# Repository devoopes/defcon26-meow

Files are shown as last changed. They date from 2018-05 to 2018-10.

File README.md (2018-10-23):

# DEFCON 26 - Maneki-neko Badge

  

photo by [Roberto Baldwin](https://twitter.com/@strngwys)  

Follow the Twitter for updates [@ManekiNekoDC](https://twitter.com/ManekiNekoDC)  

We went to DEF CON 26 and launched an unofficial DEF CON badge. We wanted to be able to create something different and unique to some of the other designs out there. The badge is controlled by an STM32 that drives the servo and dual 16 segment LEDS on the front. We attached a 3d printed arm to the servo. All the files are source code are Open Source and in this repo. You are welcome to make one yourself via OSHpark or JLC PCB. Gerber files are located in the repo.  

### Art Design:
Our art was done by Jeff Chang.
http://www.jeffchangart.com/  
Twitter [@jeffchangart](https://twitter.com/jeffchangart)  
Instagram [@jeffchangart](https://instagram.com/jeffchangart)  

All the drafts, and formats of the art can be found in the /art/ directory.

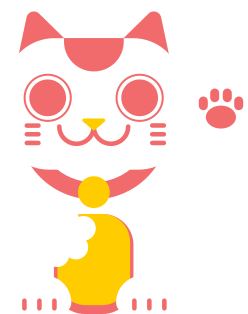
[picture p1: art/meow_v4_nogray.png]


Lanyards were done by https://customlanyards4all.com
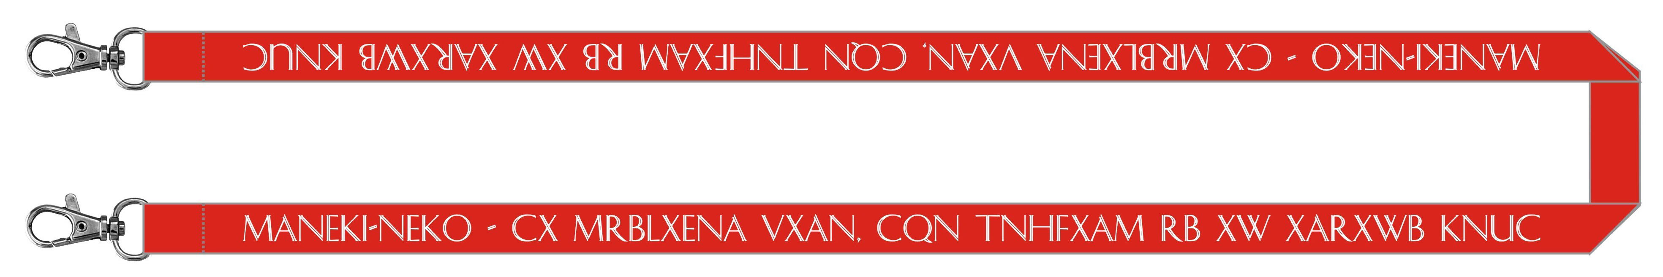
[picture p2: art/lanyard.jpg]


### Meowtronics

First done with KiCAD but abandoned after more experienced help was provided. <3 \
You can find all the Eagle files in the [eagle directory](https://github.com/SeanLeftBelow/defcon26-meow/tree/master/pcb/eagle).

Board is on [OSHpark](https://oshpark.com/shared_projects/X3Hxcson)

Guide is [here](https://github.com/SeanLeftBelow/defcon26-meow/tree/master/guide)

First look at the boards from the fab house.  
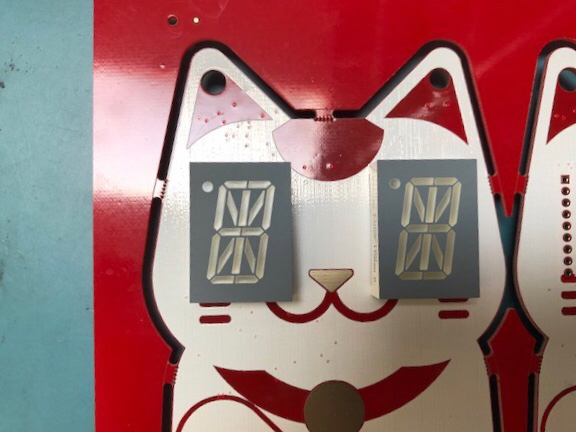
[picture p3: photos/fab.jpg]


### SAO (Special Addons/ Shitty Addons)

Overall design is a copy of the main badge. See writeup [here](https://github.com/SeanLeftBelow/defcon26-meow/tree/master/addon)

### In The Mews

[Engadget: This cute Def Con badge beckons you to hack  it](https://www.engadget.com/2018/08/15/this-cute-def-con-badge-beckons-you-to-hack-it/  ) \
[Hackaday: ALL THE BADGES OF DEF CON 26 (VOL 1)](https://hackaday.com/2018/08/14/all-the-badges-of-def-con-26-vol-1/) \
[BadgeLife - A Hackaday Documentary](https://www.youtube.com/watch?v=G2fHKRONc6U) \

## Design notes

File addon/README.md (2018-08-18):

# Overview
This folder contains the in-progress files for a Maneki-Neko "Simple* Add-On" as per the [Simple Add-On Standard](https://hackaday.com/2018/06/21/this-is-the-year-conference-badges-get-their-own-badges/).

**Note** Documentation is still in progress

BIG Thank You's go to [Contextual Electronics](https://www.youtube.com/channel/UCkJRycUz2CylxpiP-zMePow) for the YouTube Getting to Blinky Series.

This was the most useful tutorial that I referred to while going through the process. If you have the opportunity to read or watch through the entire thing before starting, I highly recommend it as this gives you a fair amount of context.

# Making the Add-On!

1. Create Project
Open KiCad and create a new project. A blank layout and schematic will be created when you create the project.

2. Open Schematic
There are many ways to do this. You can:

- Double-click the .sch file
- Click the Eeschema Launcher shortcut
- Click Command + E
- Go to Tools --> Run Eeschema

3. Create Library and Library Items
- Open Library Editor
- Create component for the connector

4. Build Schematic
- Open Schematic Editor
- Add components to the schematic: LEDs, Resistors, Connector
- Add wiring for components
- Annotate schematic
- Run Error Rule Checking

5. Create Net List

6. Create Layout
- Run PCBNew to create layout
- Go back to Schematic Editor
- Click icon for CvPcb to associate schematic components with component footprints for Layout

7. Add Footprint for Add-on connector
- Go to Footprint Editor
- Add Footprint
- Save footprint to new library
- Add Footprint Libraries Wizard

8. Layout PCB
- Layout components so that ratsnest wires do not cross connect

9. Define Edge Cut layer
(prepare for frustration, desperation, time loss, or maybe everything just goes according to plan!)
- Create DXF file for Import based on solid outline
- @TODO add details on best practices for creating a good DXF for import
- Note that dimensions should match

10. Import Silkscreen Image
- Create silkscreen as footprint and import using BMP to Component tool
- @TODO add details
- There may be some trial and error to get the dimensions to match
- 1000x1000 px resolution png with inverted colors ended up with the best results (light image dark background)
- Import to silk layer

11. Setup Copper Layers
- Create copper layers as individual images and import using BMP to Component tool
- @TODO add details
- There may be some trial and error to get the dimensions to match
- 1000x1000 px resolution png with inverted colors ended up with the best results (light image dark background)
- Import to .... F.Cu layer?

NOTES:
- The program assumes arbitrary input resolution of 300ppi, so a 300 by 300 image will give a 1" by 1" logo on the board.
- According to Best Practices, minimize the number of right angles as you layout the tracks/traces between components on your board.

Want to learn more about PCB Layout and solder mask?
https://learn.sparkfun.com/tutorials/pcb-basics/composition
https://learn.sparkfun.com/tutorials/beginners-guide-to-kicad/editing-a-pcb-layout

Other Resources and Links:
https://medium.com/@urish/a-practical-guide-to-designing-pcb-art-b5aa22926a5c

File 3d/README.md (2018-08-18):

## Arm Spec

Current badge size is 12.5 tall x 7.5 wide. Exact spec is in the eagle files.

You can find the servo horn spec online. Its very commonly available and a set standard.

Arm lengths are:
- 5.5cm tall
- 1.5cm deep
- 2cm wide

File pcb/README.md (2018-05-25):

# PCB Meow

## Libraries:
- ESP Lib: https://github.com/jdunmire/kicad-ESP8266

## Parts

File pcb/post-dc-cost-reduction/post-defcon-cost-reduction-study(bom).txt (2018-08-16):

cost reduction study

=====

no-populations only, no PCB design change

refdes	cost@50		p/n					mfg				link

sw1		0.1462		PTS645SM43SMTR92	c&k				https://www.digikey.com/product-detail/en/c-k/PTS645SM43SMTR92-LFS/CKN9112CT-ND/1146934
h1		0.7280		20021121-00010T4LF	amphenol fci	https://www.digikey.com/products/en?keywords=20021121-00010T4LF
u3		1.0010		NPTC042KFMS-RC		sullins			https://www.digikey.com/products/en?keywords=NPTC042KFMS-RC
u4		0.2368		MIC2005A-1YM5-TR	microchip		https://www.digikey.com/product-detail/en/microchip-technology/MIC2005A-1YM5-TR/576-3462-1-ND/2062462

total	2.1120

=====

cost reduction with minimal pcb design change

refdes	cost@50		p/n					mfg				notes							link

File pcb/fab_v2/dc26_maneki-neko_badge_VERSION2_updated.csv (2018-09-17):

Qty | Value | Device | Package | Parts
2 | 0 ohms | R-US_R0805 | R0805 | R1, R3
6 | 10k/5% | R-US_R0805 | R0805 | R21, R22, R26, R27, R28, R30
2 | 10uF/16V/X5R | C-USC0805 | C0805 | C1, C2
1 | 1k/5% | R-US_R0805 | R0805 | R25
6 | 1uF/16V/X7R | C-USC0805 | C0805 | C6, C7, C9, C10, C11, C12
17 | 270/5% | R-US_R0805 | R0805 | R4, R5, R6, R7, R8, R9, R10, R11, R12, R13, R14, R15, R16, R17, R18, R19, R20
1 | CIG22L4R7MNE | CIG22L4R7MNE | L-1008-US | L1
1 | JS202011SCQN | JS202011SCQN | SW_JS202011SCQN | S1
1 | PAM2301CAAB330 | PAM2301CAAB330 | SOT95P280X100-5N | U2
2 | PSA08-11SRWA | PSA08-11SRWA | PSA08-11SRWA | D1, D2
1 | RK7002BMT116 | NMOSSOT23 | SOT-23 | T1
1 | M20-7870246 | M20-7870246 | 2X2-0.1INCH-FEMALE-SMT | H3
1 | STM32F030C6T6TR | STM32F030C6T6TR | LQFP48 | U1

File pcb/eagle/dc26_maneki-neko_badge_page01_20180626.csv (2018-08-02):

Part | Value | Device | Package | Description | AVAILABILITY | DESCRIPTION | MF | MP | MPN | OC_FARNELL | OC_NEWARK | PACKAGE | PRICE | SPICEPREFIX
C1 | 10uF/16V/X5R | C-USC0805 | C0805 | CAPACITOR, American symbol |  |  |  |  |  |  |  |  |  | C
C2 | 10uF/16V/X5R | C-USC0805 | C0805 | CAPACITOR, American symbol |  |  |  |  |  |  |  |  |  | C
C3 | SHORT | C-USC0805 | C0805 | CAPACITOR, American symbol |  |  |  |  |  |  |  |  |  | C
C4 | 1uF/16V/X7R | C-USC0805 | C0805 | CAPACITOR, American symbol |  |  |  |  |  |  |  |  |  | C
C5 | 1uF/16V/X7R | C-USC0805 | C0805 | CAPACITOR, American symbol |  |  |  |  |  |  |  |  |  | C
C6 | 1uF/16V/X7R | C-USC0805 | C0805 | CAPACITOR, American symbol |  |  |  |  |  |  |  |  |  | C
C7 | 1uF/16V/X7R | C-USC0805 | C0805 | CAPACITOR, American symbol |  |  |  |  |  |  |  |  |  | C
C8 | 1uF/16V/X7R | C-USC0805 | C0805 | CAPACITOR, American symbol |  |  |  |  |  |  |  |  |  | C
C9 | 1uF/16V/X7R | C-USC0805 | C0805 | CAPACITOR, American symbol |  |  |  |  |  |  |  |  |  | C
C10 | 1uF/16V/X7R | C-USC0805 | C0805 | CAPACITOR, American symbol |  |  |  |  |  |  |  |  |  | C
C11 | 1uF/16V/X7R | C-USC0805 | C0805 | CAPACITOR, American symbol |  |  |  |  |  |  |  |  |  | C
C12 | 1uF/16V/X7R | C-USC0805 | C0805 | CAPACITOR, American symbol |  |  |  |  |  |  |  |  |  | C
D1 | PSA08-11SRWA | PSA08-11SRWA | PSA08-11SRWA
D2 | PSA08-11SRWA | PSA08-11SRWA | PSA08-11SRWA
H1 | 20021121-00010T4LF | 20021121-00010T4LF | 20021121-00010T4LF
H2 | M20-8890345R | M20-8890345R | M20-8890345R
H3 | SHITTY-ADDON-HEADER-MASTER | SHITTY-ADDON-HEADER-MASTER | 2X2-0.1INCH-FEMALE-SMT
L1 | CIG22L4R7MNE | CIG22L4R7MNE | L-1008-US
R1 | 0 | R-US_R0805 | R0805 | RESISTOR, American symbol |  |  |  |  |  |  |  |  |  | R
R2 | DNP | R-US_R0805 | R0805 | RESISTOR, American symbol |  |  |  |  |  |  |  |  |  | R
R3 | 0 | R-US_R0805 | R0805 | RESISTOR, American symbol |  |  |  |  |  |  |  |  |  | R
R4 | 270/5% | R-US_R0805 | R0805 | RESISTOR, American symbol |  |  |  |  |  |  |  |  |  | R
R5 | 270/5% | R-US_R0805 | R0805 | RESISTOR, American symbol |  |  |  |  |  |  |  |  |  | R
R6 | 270/5% | R-US_R0805 | R0805 | RESISTOR, American symbol |  |  |  |  |  |  |  |  |  | R
R7 | 270/5% | R-US_R0805 | R0805 | RESISTOR, American symbol |  |  |  |  |  |  |  |  |  | R
R8 | 270/5% | R-US_R0805 | R0805 | RESISTOR, American symbol |  |  |  |  |  |  |  |  |  | R
R9 | 270/5% | R-US_R0805 | R0805 | RESISTOR, American symbol |  |  |  |  |  |  |  |  |  | R
R10 | 270/5% | R-US_R0805 | R0805 | RESISTOR, American symbol |  |  |  |  |  |  |  |  |  | R
R11 | 270/5% | R-US_R0805 | R0805 | RESISTOR, American symbol |  |  |  |  |  |  |  |  |  | R
R12 | 270/5% | R-US_R0805 | R0805 | RESISTOR, American symbol |  |  |  |  |  |  |  |  |  | R
R13 | 270/5% | R-US_R0805 | R0805 | RESISTOR, American symbol |  |  |  |  |  |  |  |  |  | R
R14 | 270/5% | R-US_R0805 | R0805 | RESISTOR, American symbol |  |  |  |  |  |  |  |  |  | R
R15 | 270/5% | R-US_R0805 | R0805 | RESISTOR, American symbol |  |  |  |  |  |  |  |  |  | R
R16 | 270/5% | R-US_R0805 | R0805 | RESISTOR, American symbol |  |  |  |  |  |  |  |  |  | R
R17 | 270/5% | R-US_R0805 | R0805 | RESISTOR, American symbol |  |  |  |  |  |  |  |  |  | R
R18 | 270/5% | R-US_R0805 | R0805 | RESISTOR, American symbol |  |  |  |  |  |  |  |  |  | R
R19 | 270/5% | R-US_R0805 | R0805 | RESISTOR, American symbol |  |  |  |  |  |  |  |  |  | R
R20 | 270/5% | R-US_R0805 | R0805 | RESISTOR, American symbol |  |  |  |  |  |  |  |  |  | R
R21 | 10k/5% | R-US_R0805 | R0805 | RESISTOR, American symbol |  |  |  |  |  |  |  |  |  | R
R22 | 10k/5% | R-US_R0805 | R0805 | RESISTOR, American symbol |  |  |  |  |  |  |  |  |  | R
R23 | NO POP | R-US_R0805 | R0805 | RESISTOR, American symbol |  |  |  |  |  |  |  |  |  | R
R24 | NO POP | R-US_R0805 | R0805 | RESISTOR, American symbol |  |  |  |  |  |  |  |  |  | R
R25 | 1k/5% | R-US_R0805 | R0805 | RESISTOR, American symbol |  |  |  |  |  |  |  |  |  | R
R26 | 10k/5% | R-US_R0805 | R0805 | RESISTOR, American symbol |  |  |  |  |  |  |  |  |  | R
R27 | 10k/5% | R-US_R0805 | R0805 | RESISTOR, American symbol |  |  |  |  |  |  |  |  |  | R
R28 | 10k/5% | R-US_R0805 | R0805 | RESISTOR, American symbol |  |  |  |  |  |  |  |  |  | R
R29 | NO POP | R-US_R0805 | R0805 | RESISTOR, American symbol |  |  |  |  |  |  |  |  |  | R
S1 | JS202011SCQN | JS202011SCQN | SW_JS202011SCQN | JS Series DPDT On-On Gull Wing Surface Mount Subminiature Slide Switch | Good | JS Series DPDT On-On Gull Wing Surface Mount Subminiature Slide Switch | C&K Components | JS202011SCQN |  |  |  | None | 0.33 USD
SW1 | PTS645SM43SMTR92 | PTS645SM43SMTR92 | PTS645SM43SMTR92
T1 | RK7002BMT116 | NMOSSOT23 | SOT-23 | MOS FET |  |  |  |  |  | unknown | unknown
U$2 | BATTPADS-SMT | BATTPADS-SMT | BATTPADS-SMT
U1 | STM32F030C8T | STM32F030C8T | LQFP48 | ARM 32-bit Cortex™-M0 CPU
U2 | PAM2301CAAB330 | PAM2301CAAB330 | SOT95P280X100-5N
U3 | NPTC042KFMS-RC | NPTC042KFMS-RC | NPTC042KFMS-RC
U4 | MIC2005A-1YM5-TR | MIC2005A-1YM5-TR | SOT95P270X145-5N
U5 | MIC2005A-1YM5-TR | MIC2005A-1YM5-TR | SOT95P270X145-5N
U6 | MIC2005A-1YM5-TR | MIC2005A-1YM5-TR | SOT95P270X145-5N

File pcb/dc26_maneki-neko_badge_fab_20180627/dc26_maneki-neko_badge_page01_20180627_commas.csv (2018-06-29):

Designator | Manufacturer Part Number | Quantity
R1,R3 | CRG0805ZR | 2
R21,R22,R26,R27,R28 | RMCF0805JT10K0 | 5
C1,C2 | EMK212BJ106KG-T | 2
R25 | CR0805-JW-102GLF | 1
C4,C5,C6,C7,C8,C9,C10,C11,C12 | CC0805MRY5V7BB105 | 9
H1 | 20021121-00010T4LF | 1
R4,R5,R6,R7,R8,R9,R10,R11,R12,R13,R14,R15,R16,R17,R18,R19,R20 | CR0805-JW-271ELF | 17
L1 | CIG22L4R7MNE | 1
H2 | M20-8890345R | 1
U4,U5,U6 | MIC2005A-1YM5-TR | 3
U3 | NPTC042KFMS-RC | 1
U2 | PAM2301CAAB330 | 1
D1,D2 | PSA08-11SRWA | 2
T1 | RK7002BMT116 | 1
H3 | NPTC022KFMS-RC | 1
U1 | STM32F030C8T6 | 1
S1 | JS202011SCQN | 1
SW1 | PTS645SM43SMTR92 LFS | 1

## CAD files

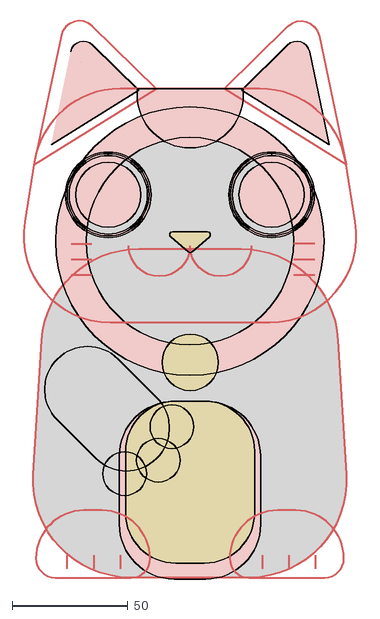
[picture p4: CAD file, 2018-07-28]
art/working files/meow_v4-trace.dxf
150.4 x 243.4

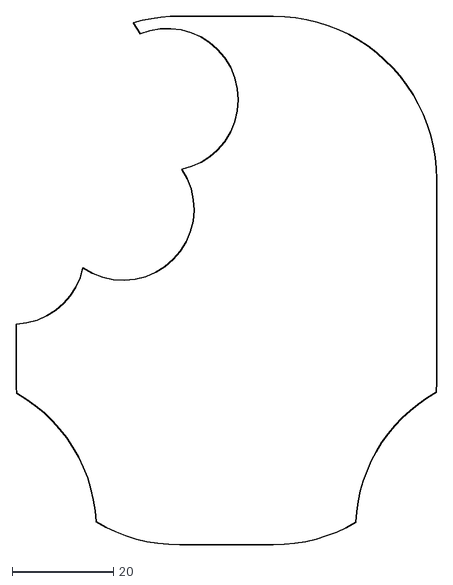
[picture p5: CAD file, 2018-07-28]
pcb/eagle/art prep/meow_v4_coin_fixed.dxf
83.2 x 104.6

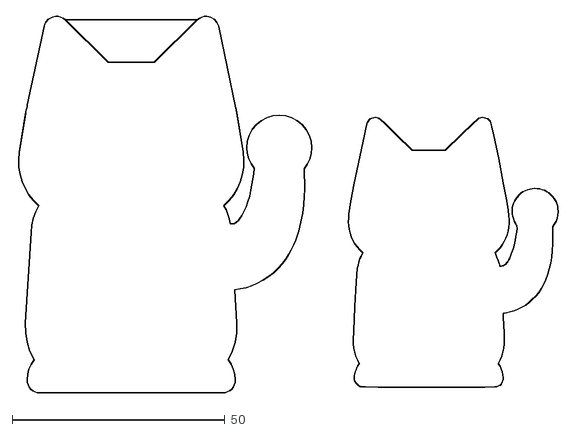
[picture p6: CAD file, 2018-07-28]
art/meow_v4_linedraw-outline-2.5.dxf
127.4 x 88.5

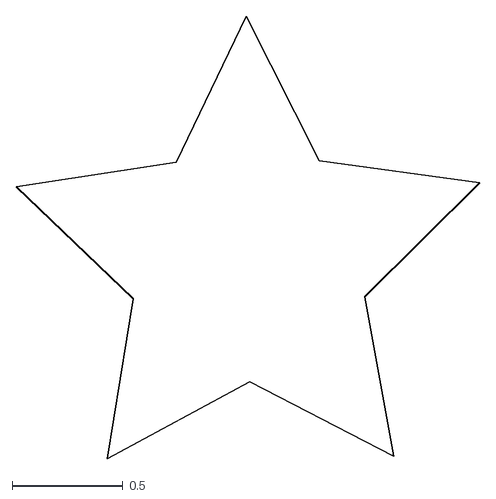
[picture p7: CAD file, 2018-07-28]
art/working files/star.dxf
2.10 x 2.00

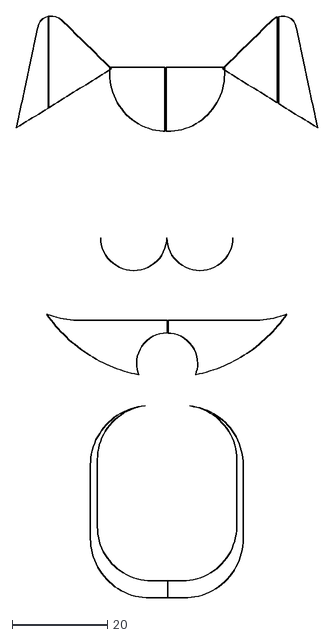
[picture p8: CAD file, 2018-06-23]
pcb/eagle/art prep/meow_v4_redfill2.dxf
63.3 x 122.4

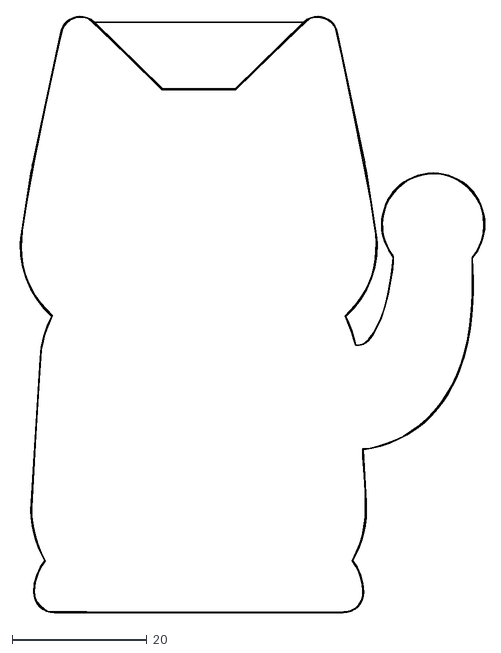
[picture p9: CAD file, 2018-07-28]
art/meow_v4_linedraw-outline.dxf
69.5 x 88.5

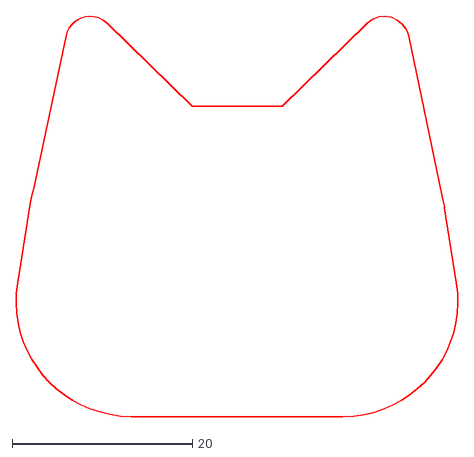
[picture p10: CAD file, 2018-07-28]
art/working files/meow_v5-thick outline-face.dxf
49.1 x 44.5

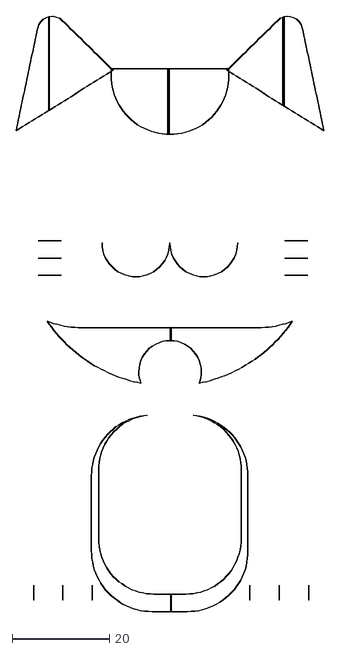
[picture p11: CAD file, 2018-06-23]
pcb/eagle/art prep/meow_v4_redfill.dxf
63.3 x 122.4

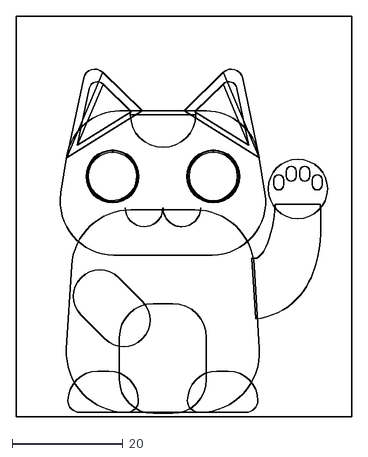
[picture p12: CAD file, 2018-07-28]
art/meow_v4_silk-invert-cu.dxf
60.6 x 72.4

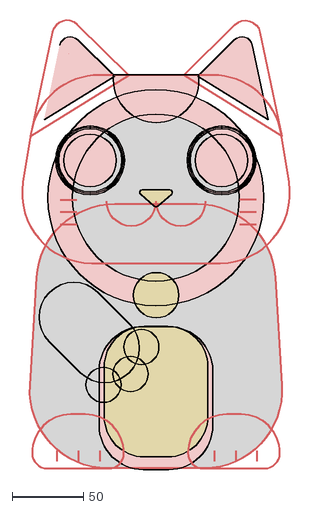
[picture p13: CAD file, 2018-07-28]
art/working files/meow_v4-export.dxf
195.9 x 317.1

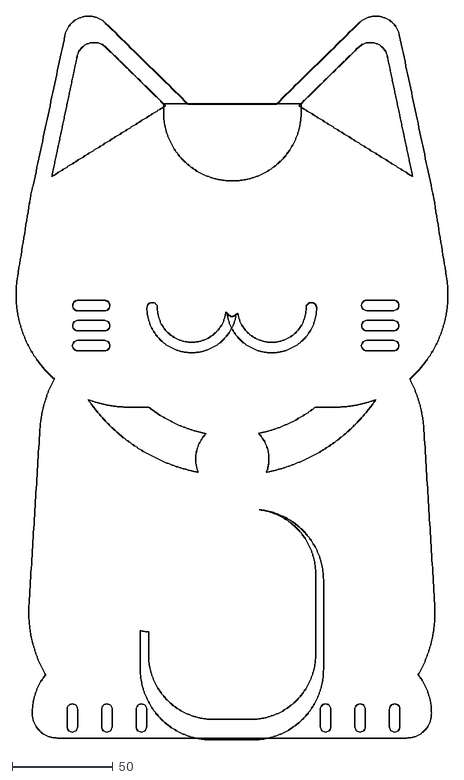
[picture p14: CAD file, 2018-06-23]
pcb/eagle/art prep/meow_v4_silkstop(red).dxf
214.8 x 360.0

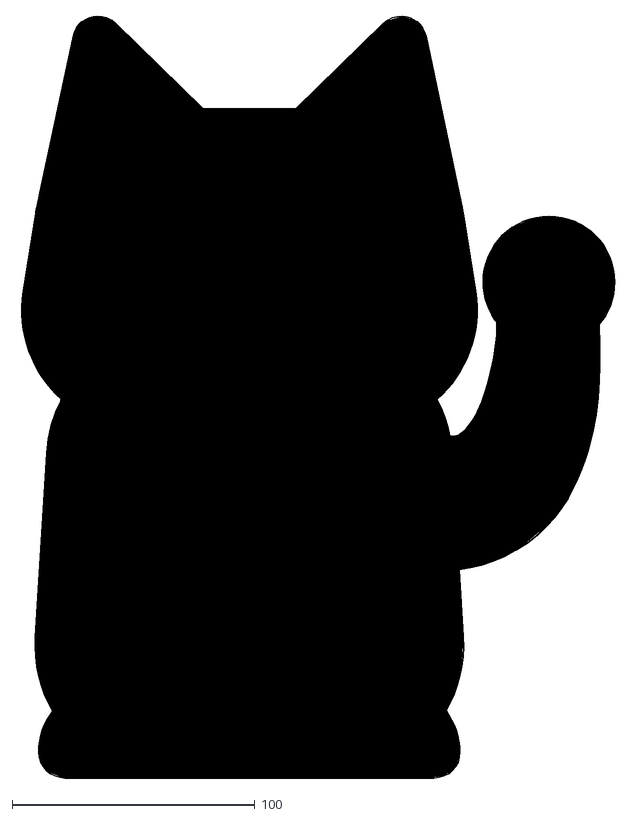
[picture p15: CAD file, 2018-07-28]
art/meow_v4_mask.dxf
246.3 x 313.6

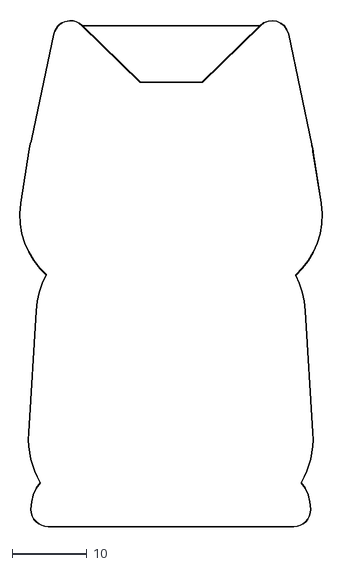
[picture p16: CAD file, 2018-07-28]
art/working files/meow_v5-thick outline.dxf
41.6 x 68.5

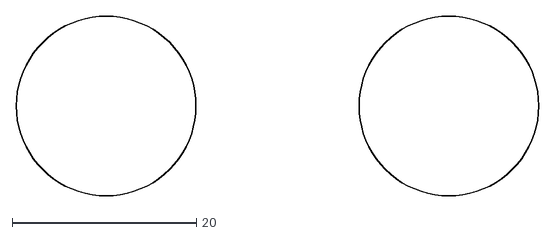
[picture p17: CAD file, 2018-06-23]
pcb/eagle/art prep/meow_v4_eyes.dxf
56.6 x 19.5

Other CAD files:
art/working files/star-lg.dxf
pcb/eagle/art prep/meow_v4_boardoutline.dxf
art/working files/meow_v4.dxf
art/meow_v4_mask-copy.dxf

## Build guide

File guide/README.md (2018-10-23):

# Maneki-neko Badge Assembly Guide

A few have been asking for the ability to build their own from parts. This is a guide to do so.

# DISCLAIMER:
This project is not for the soldering beginner. All the parts are [0603](https://en.wikipedia.org/wiki/Surface-mount_technology#Packages) which are about the size of a grain of sand.

If you wanted to order parts yourself, [Mouser](https://www.mouser.com/) and [Digi-Key](https://www.digikey.com/) are my main resources for parts.

The Bill of Materials (BOM) can be found [here](https://github.com/SeanLeftBelow/defcon26-meow/blob/master/pcb/dc26_maneki-neko_badge_fab_20180627/dc26_maneki-neko_badge_page01_20180627_commas.csv). Sometimes manufacturers discontinue parts or they simply become unavailable. You will have to find alt parts. In my recent order I put together a spreadsheet of purchasable parts and some alts I chose. Speedsheet is [here](https://docs.google.com/spreadsheets/d/13uPpL5BdiQRk4fQEPqo-OPYJxFrPVoP4QA09e1TaAkI/edit?usp=sharing)

If parts become unavailable you can create a PR or DM me on twitter [@ManekiNekoDC](https://twitter.com/ManekiNekoDC) \

## Important Notes about the BOM
- U4,U5,U6, IC PWR SWITCH ACTIVE HI \
    _This part was removed on the second rev of the board and has no place on the board._
- H3	Header 4 Position Dual Row \
    _This part was removed in ver 2 but the pads are still there._
- R30, 10K OHM \
    _This part is only on ver 2._

## Required tools
Soldering Iron with a fine tip (Something you are comfortable working with 0603's with.)\
Leaded/Unleaded Solder \
[Flux](https://www.amazon.com/Tools-Harware-8310000186-Kester-Soldering/dp/B00YL1D3US/) \
[Solder Wick](https://www.amazon.com/NTE-Electronics-SW02-10-No-Clean-Blue-098/dp/B0195UVWJ8/) \
[Tweezers](https://www.amazon.com/gp/product/B0009K3IAK/) (Get good ones. Bad ones can be magnetic.) \
[Magnified Glass](https://www.amazon.com/Spectrum-Natural-Daylight-Magnifier-Mounting/dp/B00D5WM8EG/) or [Microscope](https://www.amazon.com/gp/product/B005C75IVM/) \
[The Programmer](https://www.segger.com/products/debug-probes/j-link/models/j-link-edu-mini/) -  [Amazon](https://www.amazon.com/Segger-J-Link-EDU-mini-Debugger/dp/B0758XRMTF) /  [Adafruit](https://www.adafruit.com/product/3571) \
I used a Segger, but you can get cheaper AVR programmers off Ali and Amazon.

## Soldering the board.
- (**U1**	MCU 32-bit STM32F ARM Cortex) \
_Note: Liberally apply flux when soldering the MCU. If you have not soldered an MCU before please watch a few techniques on YouTube._  
Position the PCB so the head is up and feet down. The MCU is in the top right and the position of the dot is lower left.
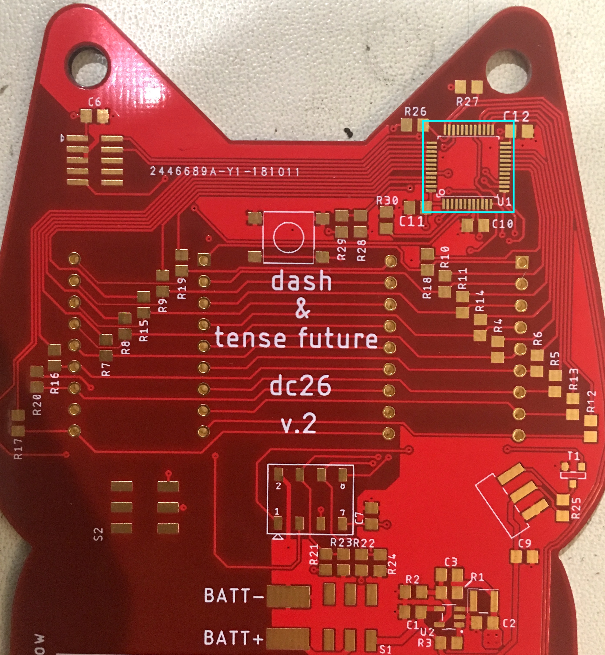
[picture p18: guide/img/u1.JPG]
  

- (**R1,R3** - 0 OHM) \
_Note: R2 and R4 are intentionally left blank_
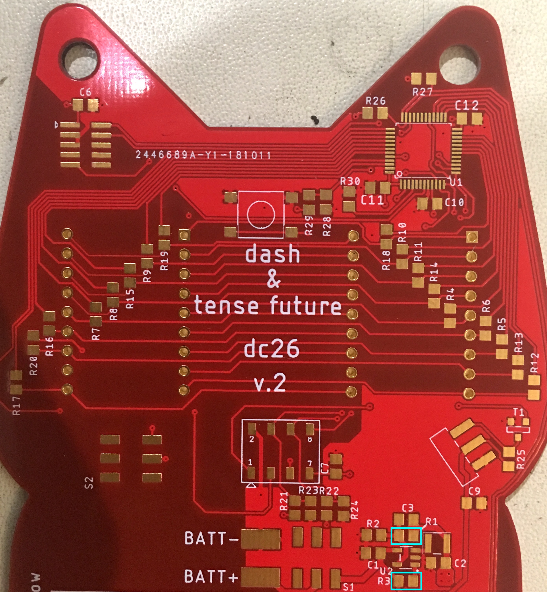
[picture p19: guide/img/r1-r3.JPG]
  

- (**R21,R22,R26,R27,R28,R30**	10K OHM) \
_Note: R23, R24, R29 are intentionally left blank_
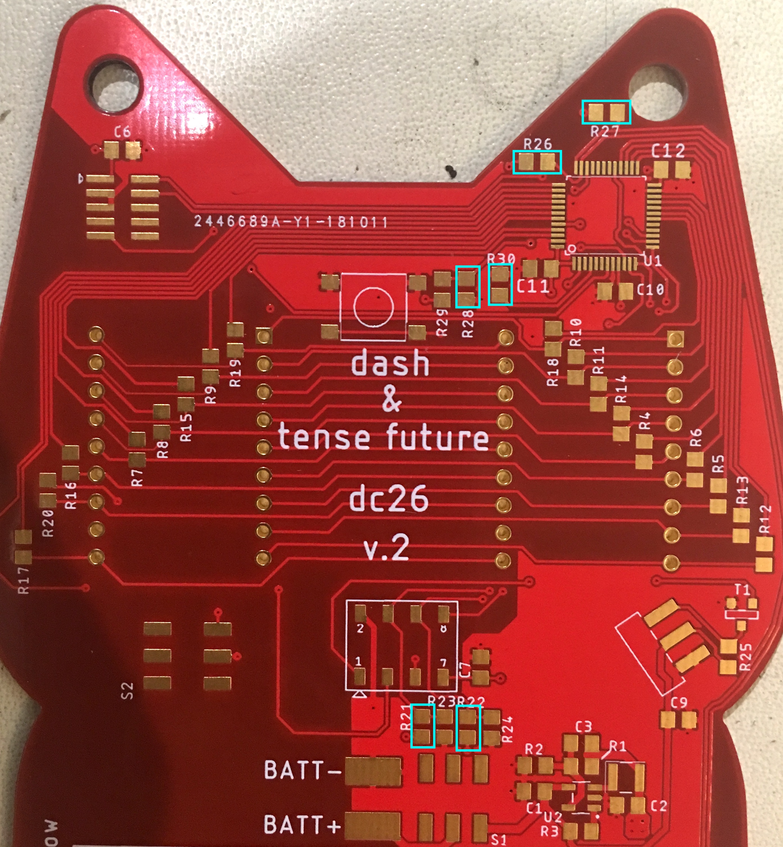
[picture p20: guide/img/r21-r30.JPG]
  

- (**C1,C2** - 10µF ±10% 16V) \
_Note: C3 is intentionally left blank_
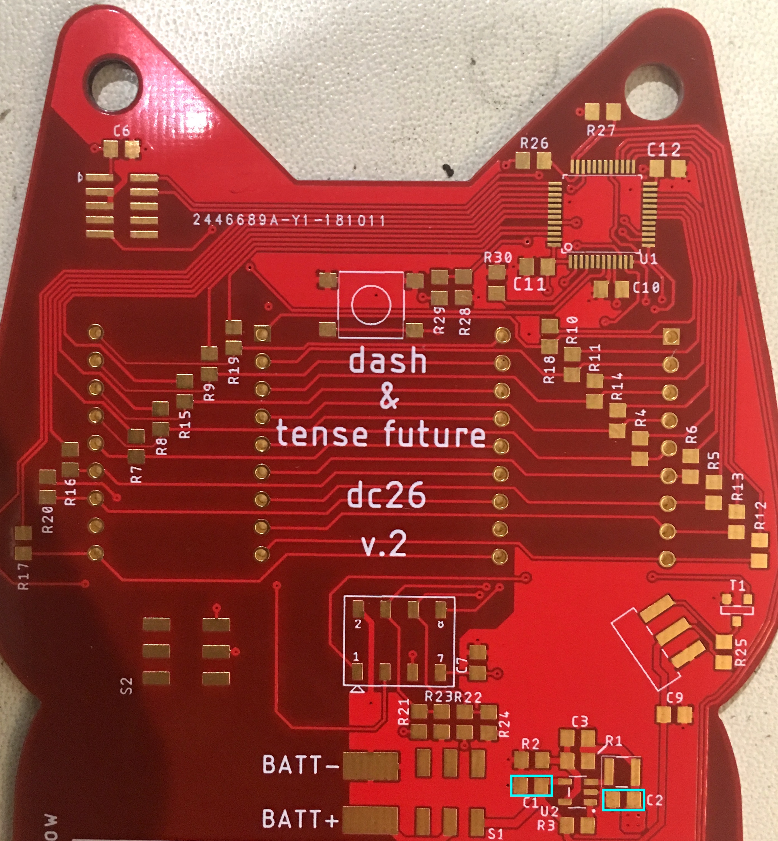
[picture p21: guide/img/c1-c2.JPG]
  

- (**R25** - 1K OHM)
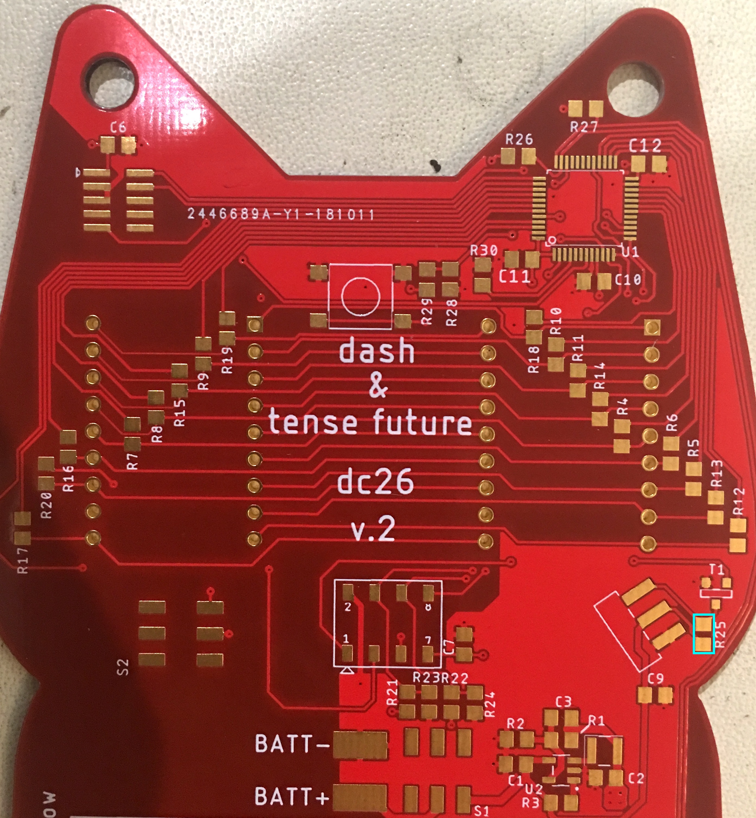
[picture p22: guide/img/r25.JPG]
  

- (**C4,C5,C6,C7,C8,C9,C10,C11,C12**-  1uF 16V) \
_Note: C4, C5, C8 were removed on rev 2_
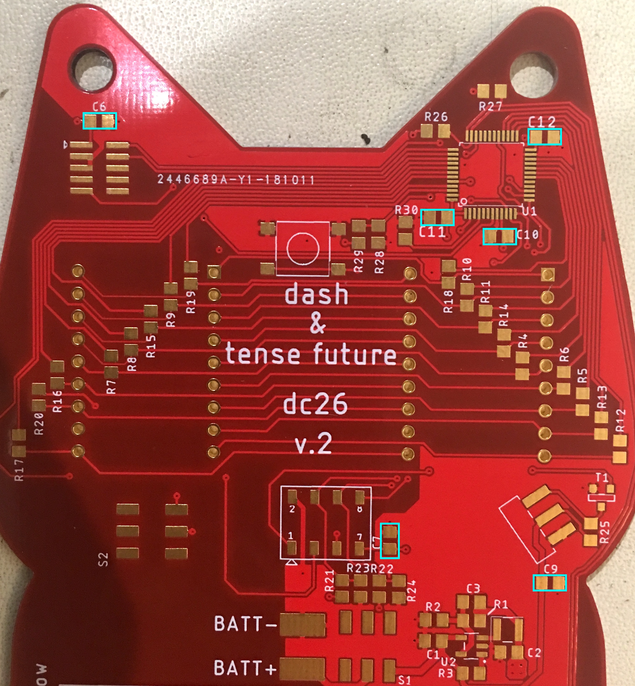
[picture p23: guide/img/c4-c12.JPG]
  

- (**H1**	- 2 Row 10 Position (5x2) 1.27 mm Unshrouded Surface Mount Male Pin Header)
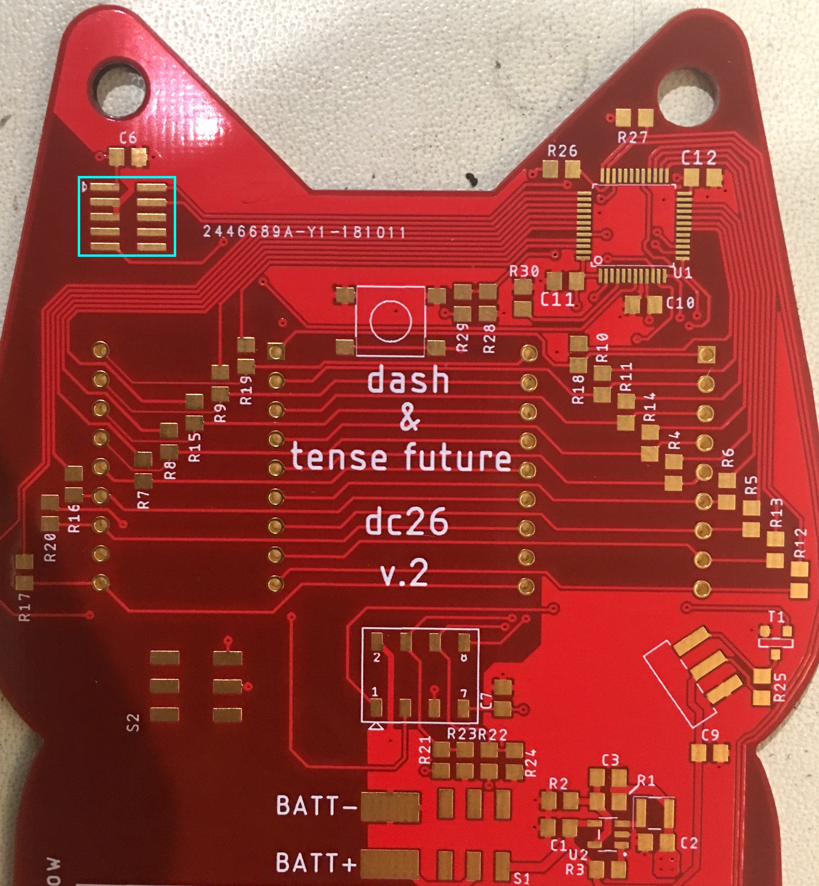
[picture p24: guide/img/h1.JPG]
  

- (**R4,R5,R6,R7,R8,R9,R10,R11,R12,R13,R14,R15,R16,R17,R18,R19,R20**	- 270 OHM)
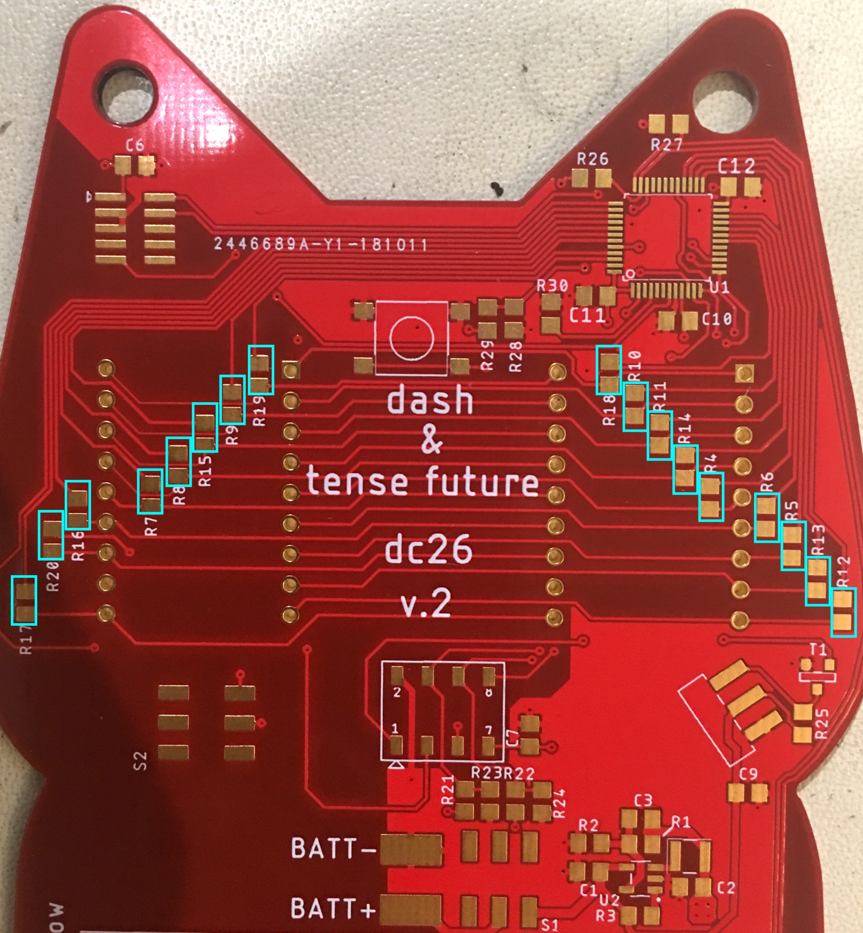
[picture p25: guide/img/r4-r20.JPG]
  

- (**L1**	- 4.7µH Shielded Multilayer Inductor 1.1A) \
_Note: No silkscreen label_
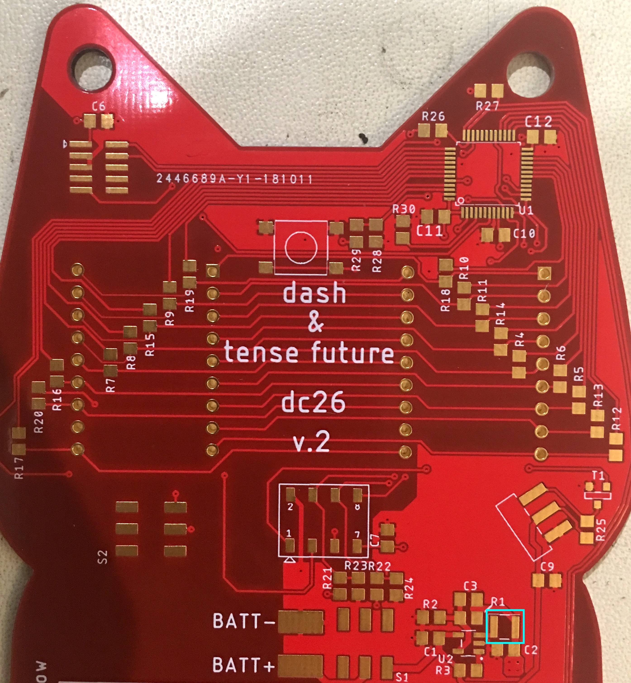
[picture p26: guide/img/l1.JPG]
  

- (**U2**	- IC REG BCK 3.3V 0.8A SYNC)
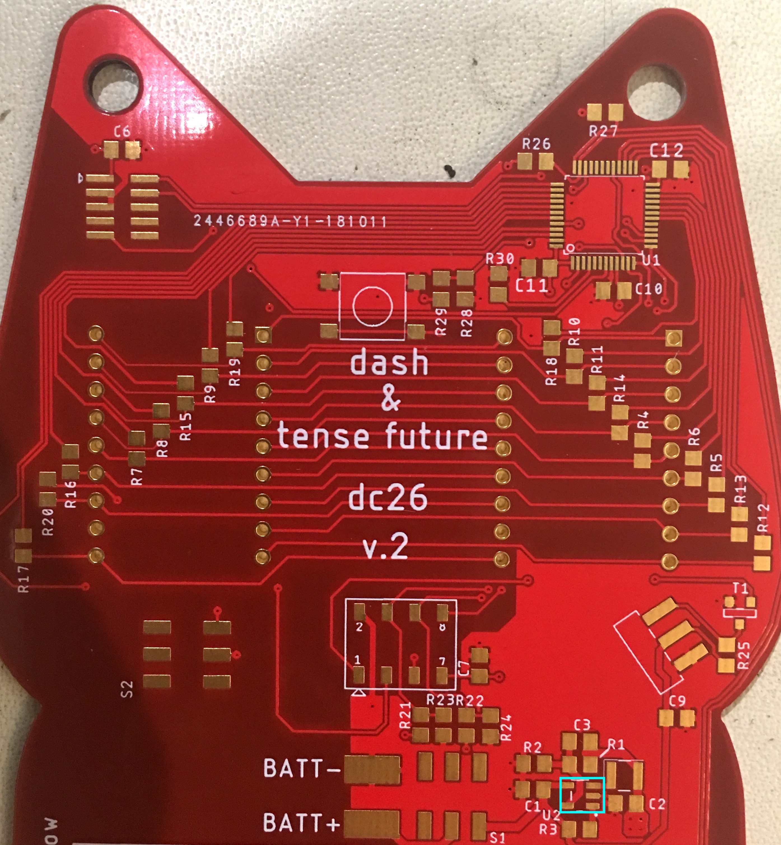
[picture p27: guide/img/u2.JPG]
  

- (**T1**	- 2.5V Drive Nch Mosfet)
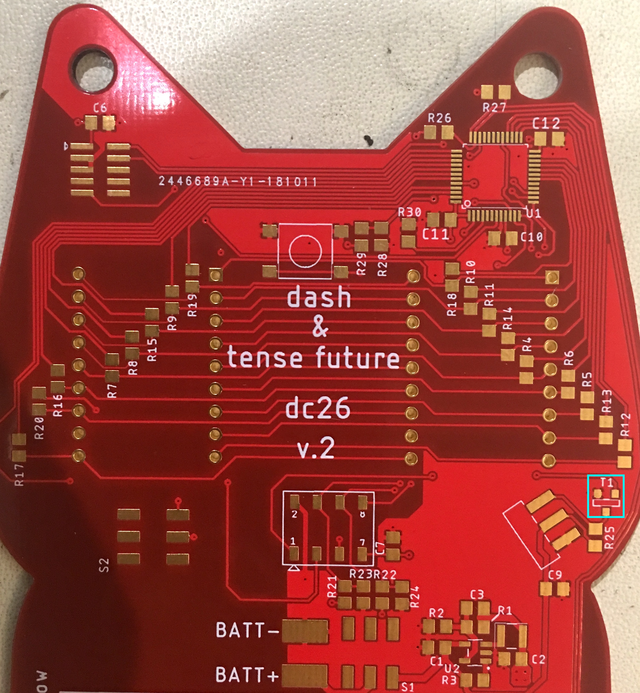
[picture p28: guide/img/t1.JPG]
  

- (**S1** - Switch) \
_Note: This is to the right of the BATT pads. The close up is to show orientation for the off position_
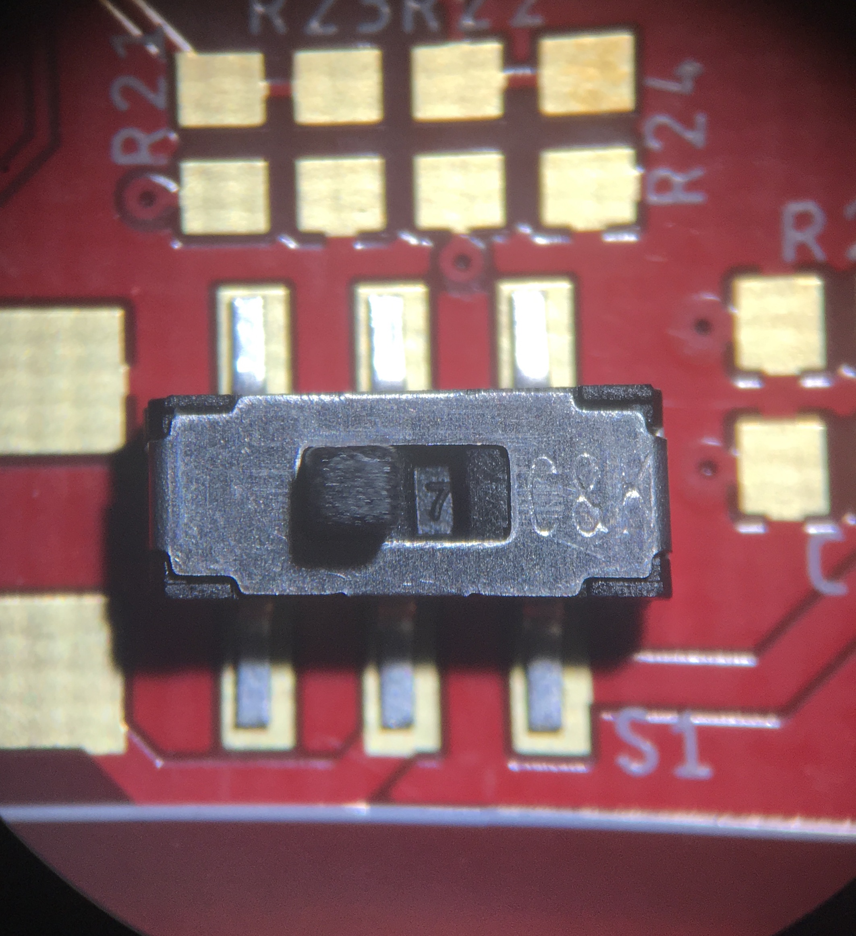
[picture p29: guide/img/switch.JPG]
  

# These parts should be soldered last.

- (**H3**	- Header 4 Position Dual Row)
  

- (**D1,D2** - 16 Segment Display; red) \
_Note: The orientation of the dot is always bottom right_
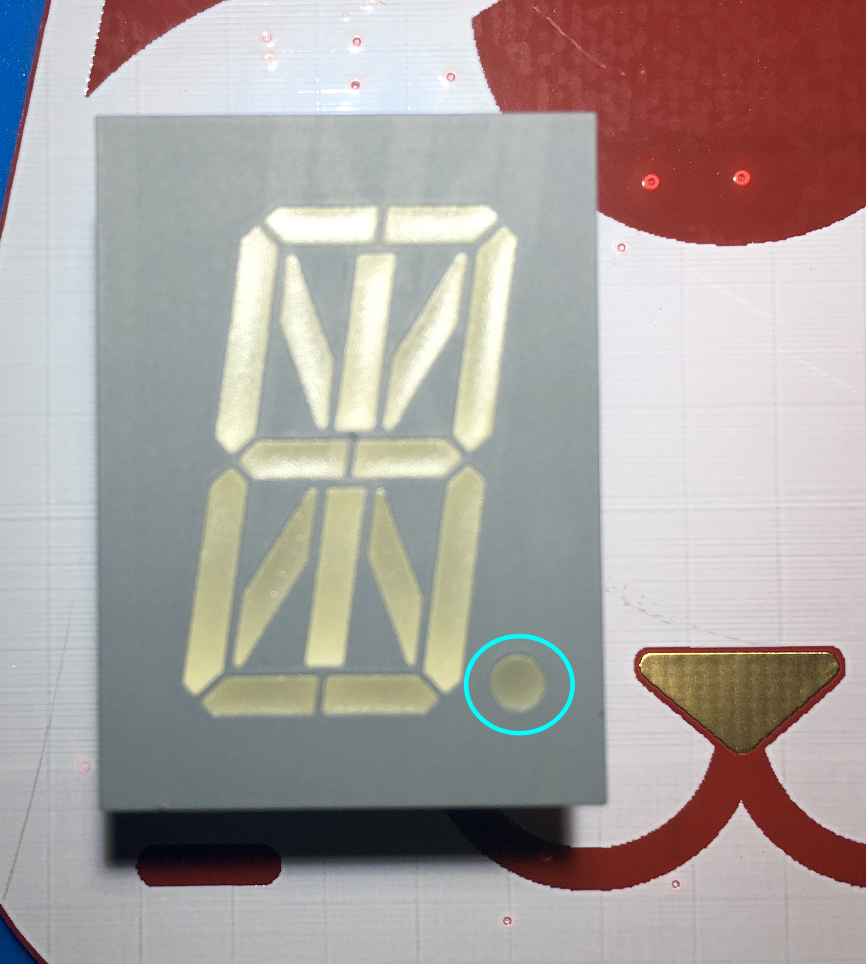
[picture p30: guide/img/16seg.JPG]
  

- (Battery Pack)
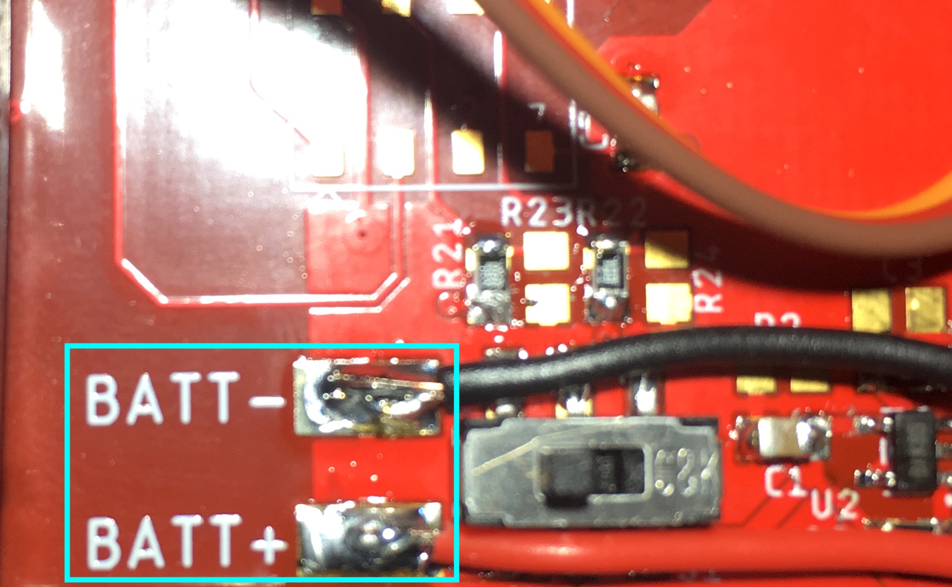
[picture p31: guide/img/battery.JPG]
  

- (Servo) \
_Note: from top to bottom Orange, Red, Brown._
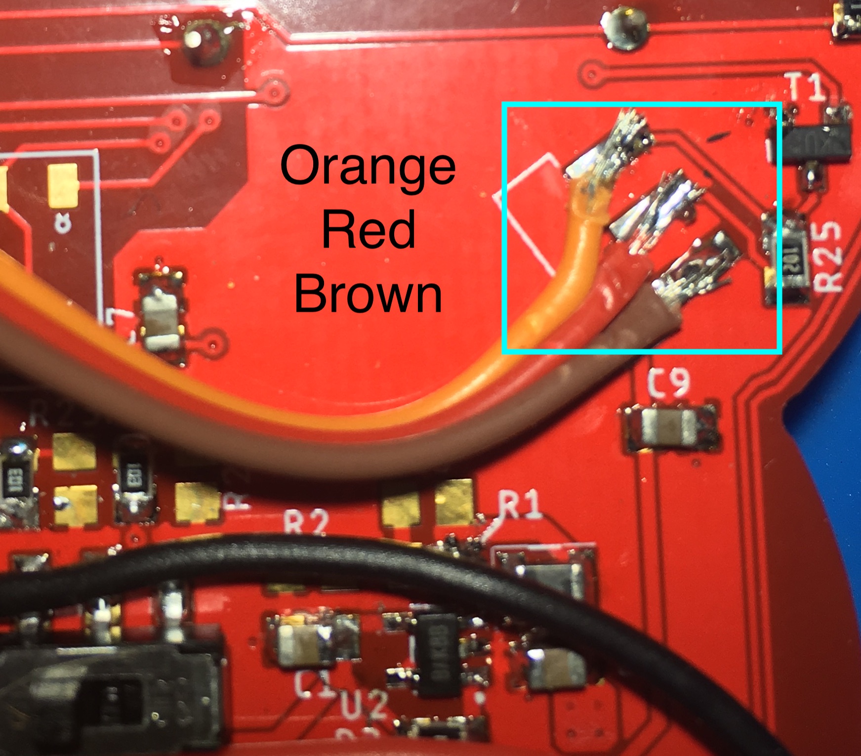
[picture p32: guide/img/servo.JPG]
  

- Once everything is soldered, attach the battery pack and servo with double sided foam tape. The servo will fit perfectly alongside the battery pack.
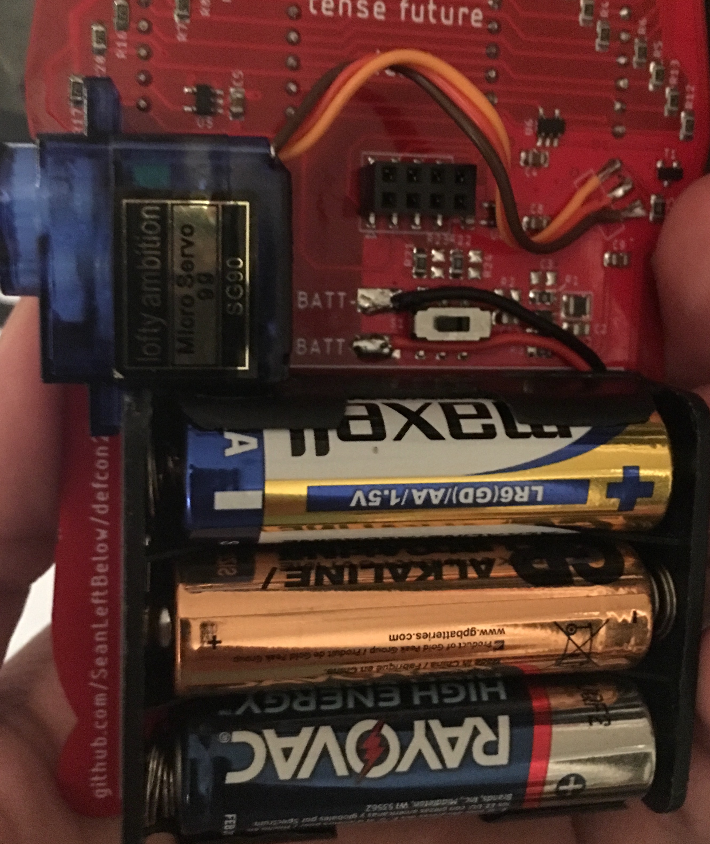
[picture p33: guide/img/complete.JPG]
  

## Keil Setup:

On a windows computer download and install [Keil](http://www2.keil.com/stmicroelectronics-stm32/mdk) \
_Note: in the case this becomes unavailable or the link changes. Google for the `ARM Keil tool for MDK for STM32L0 and STM32F0`_ \
On the same computer clone this repo and open the firmware directory of the repo in Keil.

## Programming the Board.

If you would like to attach a programmer with out having the fitting for the small ribbon the full schematic is available in eagle.

| | | | |
| --- | :---: | :---: | --- |
| v3.3 | **1** | **2** | DLO |
| GND  | **3** | **4** | CLK |
| GND  | **5** | **6** | |
| | **7** | **8** | |
| RST  | **9** | **10** | | |

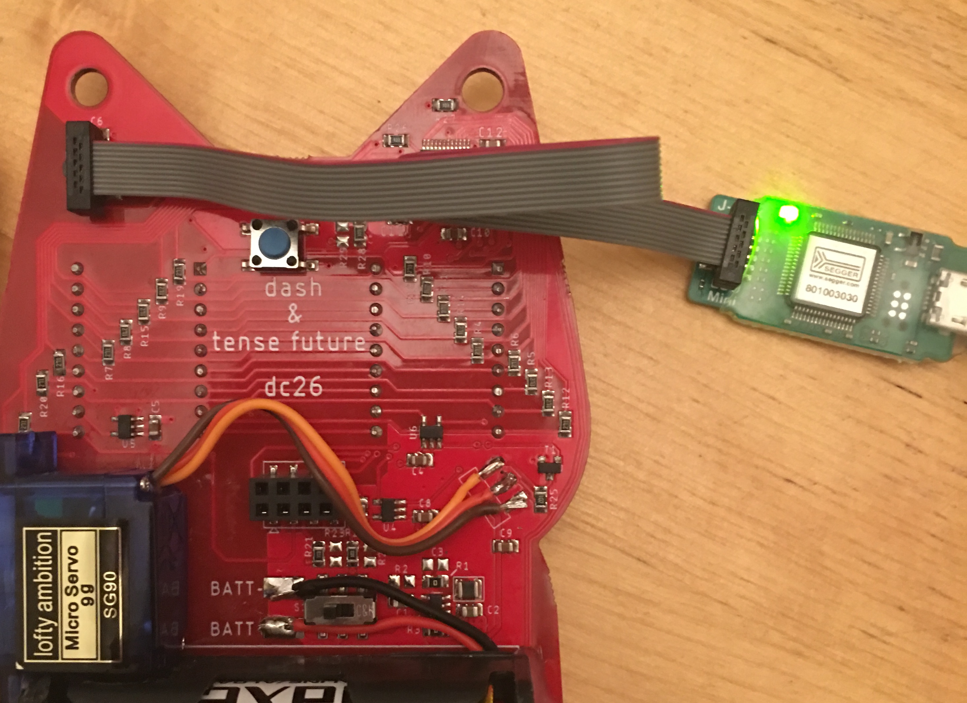
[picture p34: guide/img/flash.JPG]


_Note: Please note the orientation of the ribbon cable._ \
Once Keil is setup, put in batteries, attach the programmer cable and turn the switch to the right. Then click the `LOAD` button in Keil. A prompt will appear with a ToS that you have to accept.
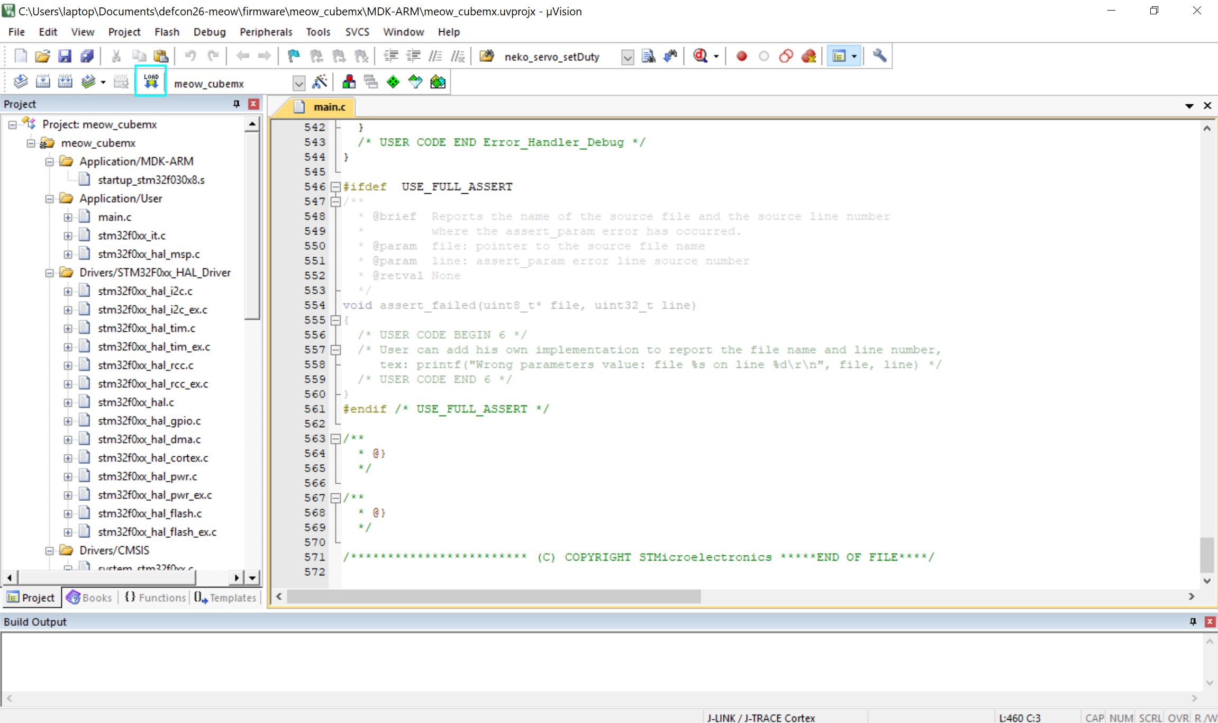
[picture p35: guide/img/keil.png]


If everything is soldered correctly and it's powered it will begin to flash. Once it's programmed the servo will start moving and the eyes will flash.

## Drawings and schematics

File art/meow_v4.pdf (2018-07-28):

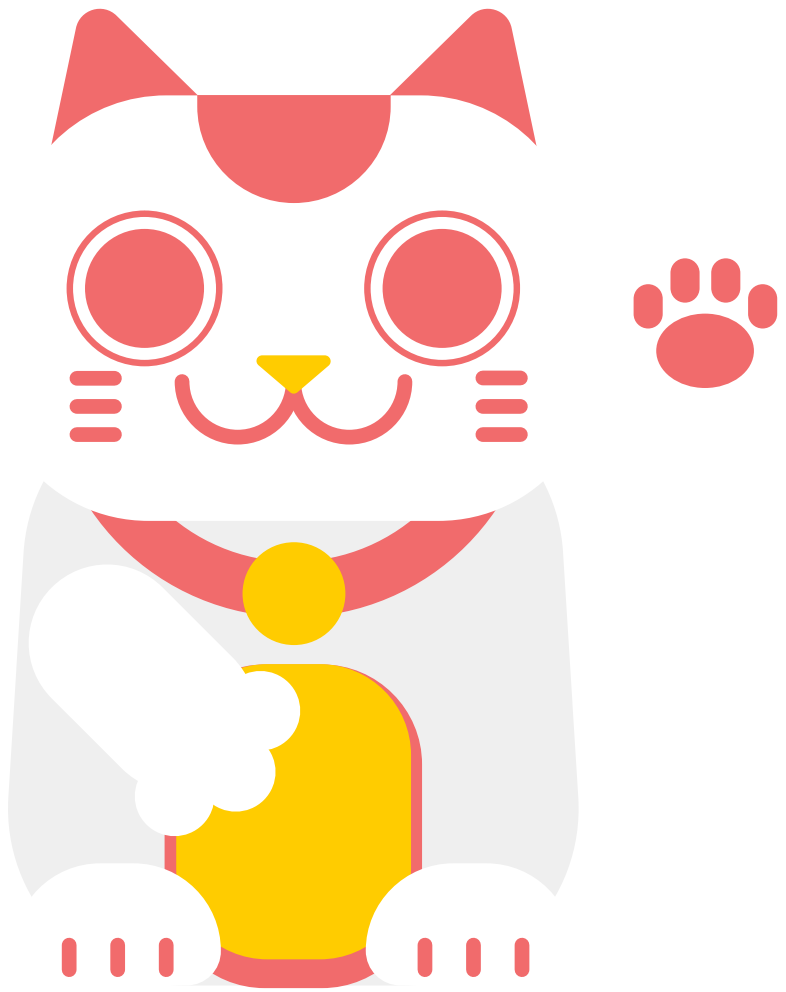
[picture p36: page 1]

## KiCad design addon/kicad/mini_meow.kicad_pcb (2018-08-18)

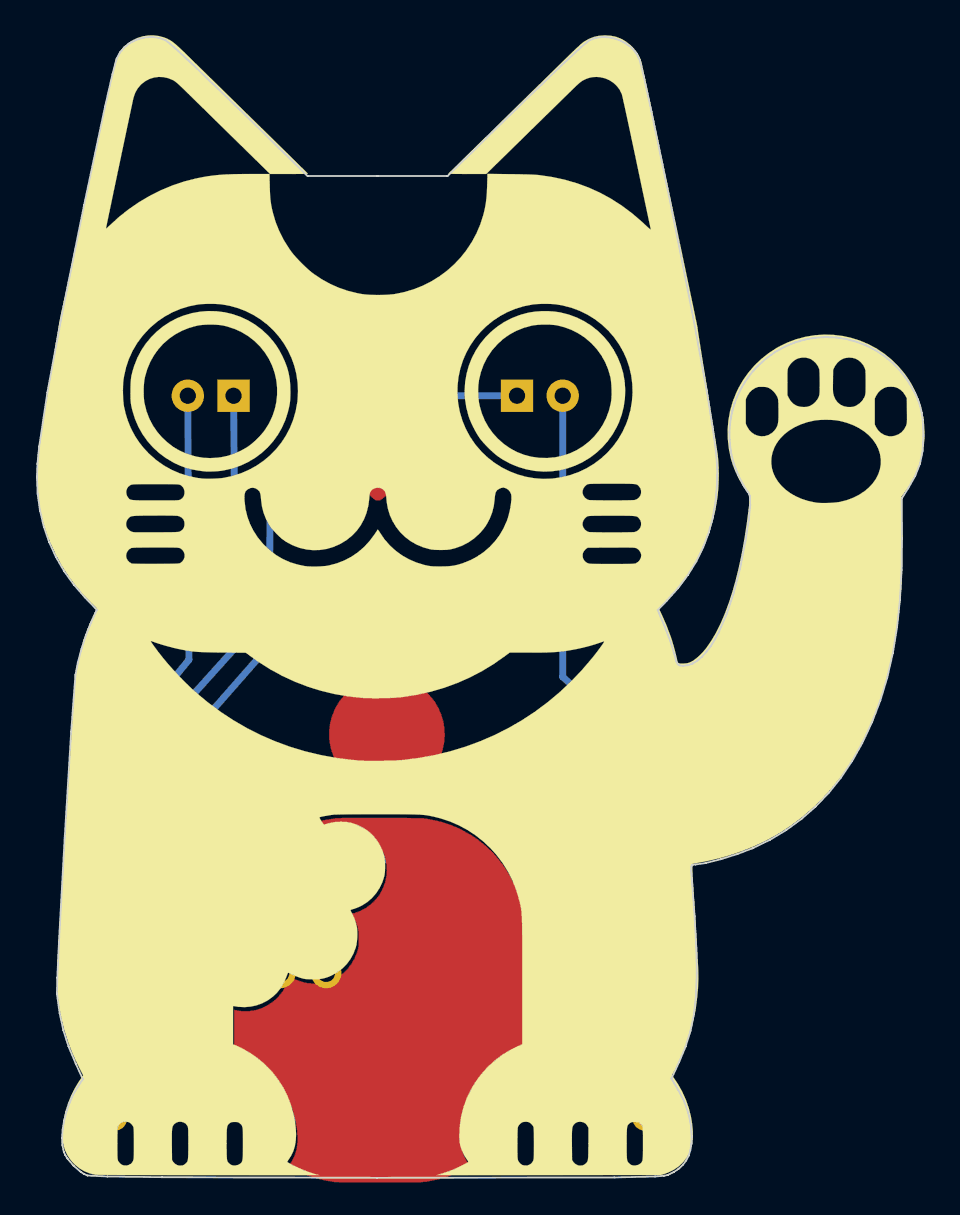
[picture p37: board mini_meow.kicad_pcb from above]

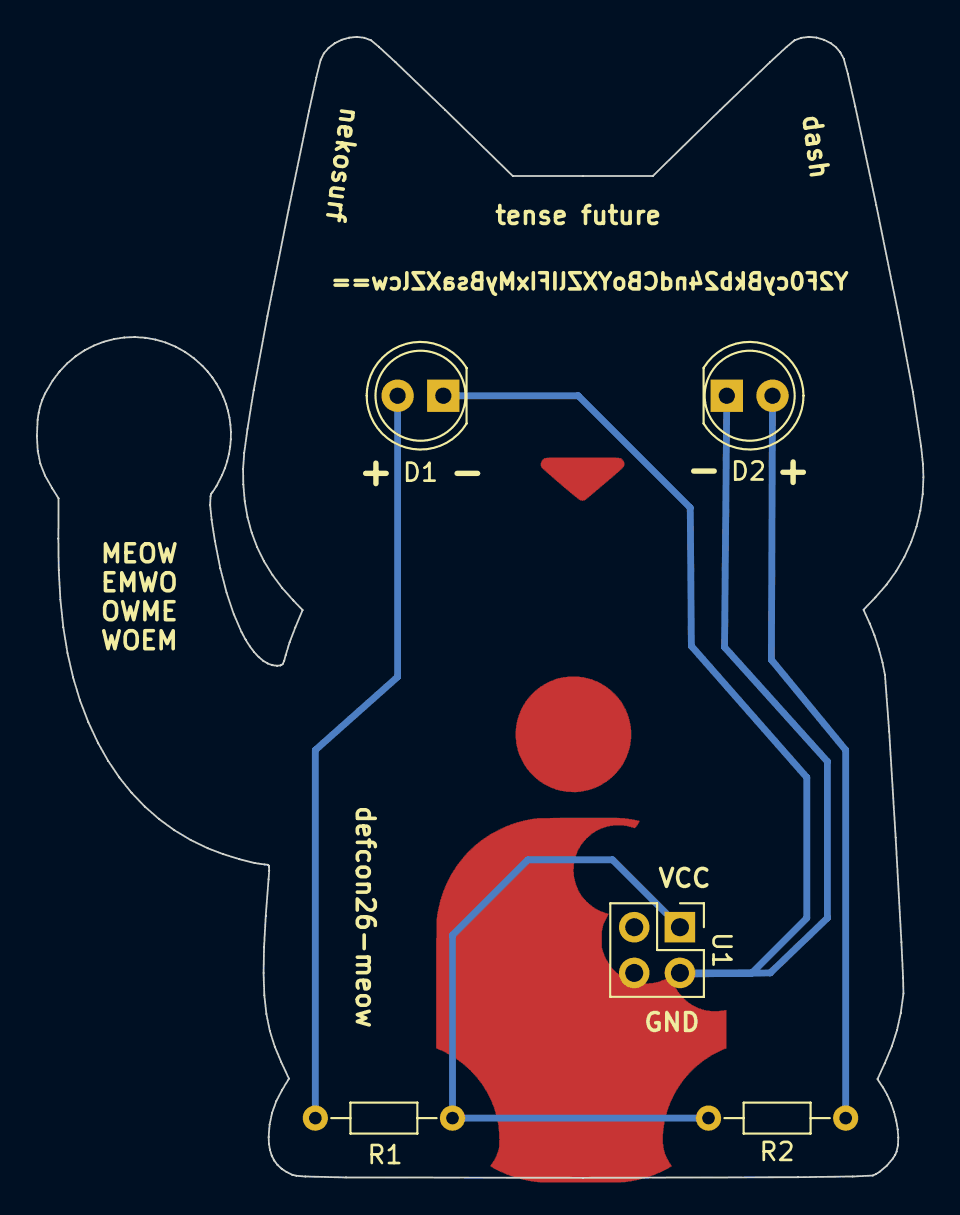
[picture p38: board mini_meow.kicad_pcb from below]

Board: 2 copper layers, 49.3 x 63.4 mm, 5 parts (5 on the bottom side), 4 nets.

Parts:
D1, D2: LED; LED_D5.0mm
R1, R2: 65; R_Axial_DIN0204_L3.6mm_D1.6mm_P7.62mm_Horizontal
U1: sa_connector; Pin_Header_Straight_2x02_Pitch2.54mm

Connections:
+3V3: R1.2, R2.2, U1.1
GND: D1.1, D2.1, U1.2
unnamed: D1.2, R1.1
unnamed: D2.2, R2.1

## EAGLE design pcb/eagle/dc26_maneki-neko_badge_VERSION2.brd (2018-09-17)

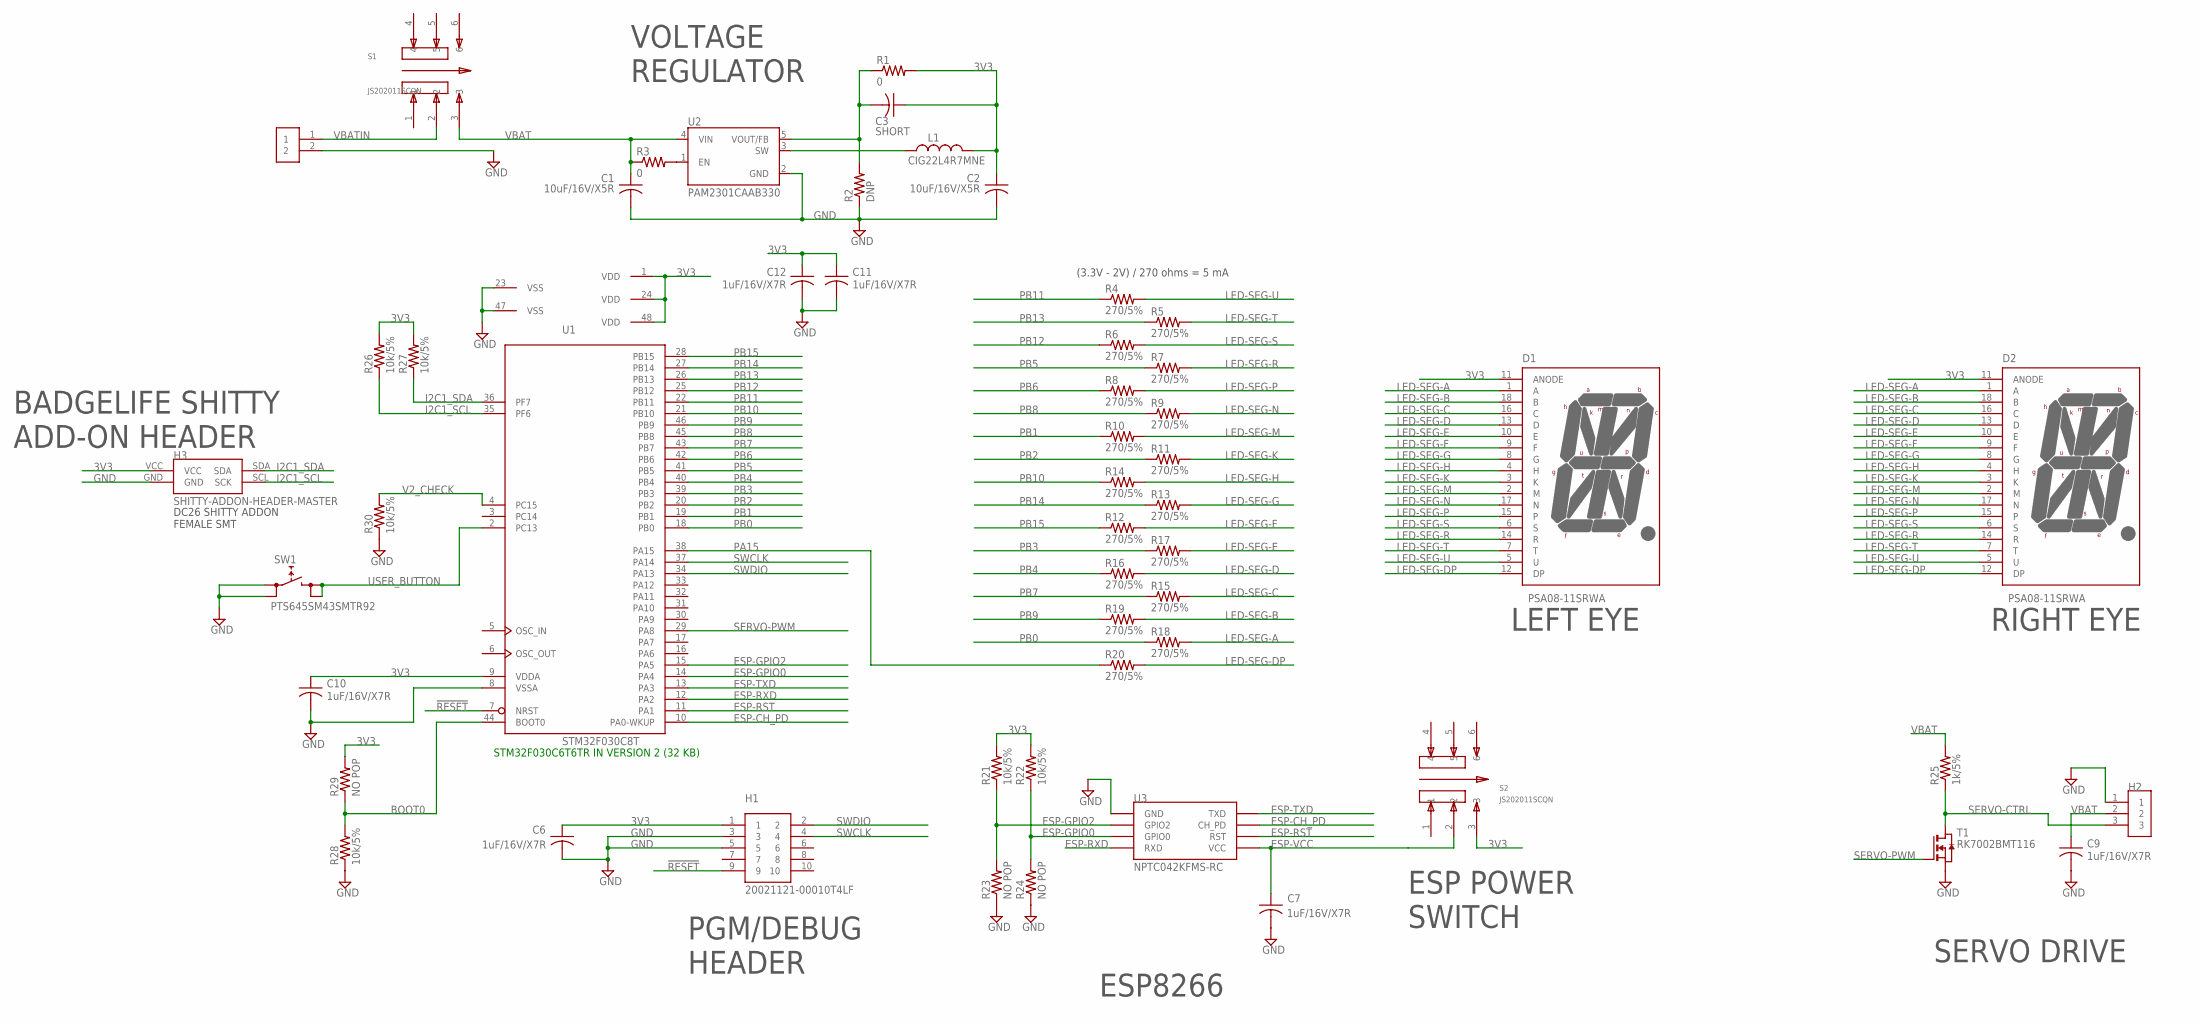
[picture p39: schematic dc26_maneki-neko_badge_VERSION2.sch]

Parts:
C1, C2: 10uF/16V/X5R; C0805
C3: SHORT; C0805
C6, C7, C9, C10, C11, C12: 1uF/16V/X7R; C0805
D1, D2: PSA08-11SRWA
H1: 20021121-00010T4LF
H2: M20-8890345R
H3: SHITTY-ADDON-HEADER-MASTER; 2X2-0.1INCH-FEMALE-SMT
H4: BATTPADS-SMT
L1: CIG22L4R7MNE; L-1008-US
R1, R3: 0; R0805
R2: DNP; R0805
R4, R5, R6, R7, R8, R9, R10, R11, R12, R13, R14, R15, R16, R17, R18, R19, R20: 270/5%; R0805
R21, R22, R26, R27, R28, R30: 10k/5%; R0805
R23, R24, R29: NO POP; R0805
R25: 1k/5%; R0805
S1, S2: JS202011SCQN; SW_JS202011SCQN
SW1: PTS645SM43SMTR92
T1: RK7002BMT116; SOT-23
U1: STM32F030C8T; LQFP48
U2: PAM2301CAAB330; SOT95P280X100-5N
U3: NPTC042KFMS-RC

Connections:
3V3: C2.1, C3.1, C6.1, C10.1, C11.1, C12.1, D1.11 (ANODE), D2.11 (ANODE), H1.1, H3.VCC, L1.P$2 (2), R1.2, R21.2, R22.2, R26.2, R27.2, R29.2, S2.3, U1.1 (VDD), U1.9 (VDDA), U1.24 (VDD), U1.48 (VDD)
!RESET: H1.9, U1.7 (NRST)
BOOT0: R28.2, R29.1, U1.44 (BOOT0)
ESP-CH_PD: U1.10 (PA0-WKUP), U3.3 (CH_PD)
ESP-GPIO0: R22.1, R24.2, U1.14 (PA4), U3.6 (GPIO0)
ESP-GPIO2: R21.1, R23.2, U1.15 (PA5), U3.4 (GPIO2)
ESP-RST: U1.11 (PA1), U3.5 (RST)
ESP-RXD: U1.12 (PA2), U3.8 (RXD)
ESP-TXD: U1.13 (PA3), U3.1 (TXD)
ESP-VCC: C7.1, S2.2, U3.7 (VCC)
GND: C1.2, C2.2, C6.2, C7.2, C9.2, C10.2, C11.2, C12.2, H1.3, H1.5, H2.1, H3.GND, H4.2, R2.1, R23.1, R24.1, R28.1, R30.1, SW1.1 (0), SW1.2 (0), T1.2 (S), U1.8 (VSSA), U1.23 (VSS), U1.47 (VSS), U2.2 (GND), U3.2 (GND)
I2C1_SCL: H3.SCL (SCK), R26.1, U1.35 (PF6)
I2C1_SDA: H3.SDA, R27.1, U1.36 (PF7)
LED-SEG-A: D1.1 (A), D2.1 (A), R18.2
LED-SEG-B: D1.18 (B), D2.18 (B), R19.2
LED-SEG-C: D1.16 (C), D2.16 (C), R15.2
LED-SEG-D: D1.13 (D), D2.13 (D), R16.2
LED-SEG-DP: D1.12 (DP), D2.12 (DP), R20.2
LED-SEG-E: D1.10 (E), D2.10 (E), R17.2
LED-SEG-F: D1.9 (F), D2.9 (F), R12.2
LED-SEG-G: D1.8 (G), D2.8 (G), R13.2
LED-SEG-H: D1.4 (H), D2.4 (H), R14.2
LED-SEG-K: D1.3 (K), D2.3 (K), R11.2
LED-SEG-M: D1.2 (M), D2.2 (M), R10.2
LED-SEG-N: D1.17 (N), D2.17 (N), R9.2
LED-SEG-P: D1.15, D2.15, R8.2
LED-SEG-R: D1.14 (R), D2.14 (R), R7.2
LED-SEG-S: D1.6 (S), D2.6 (S), R6.2
LED-SEG-T: D1.7 (T), D2.7 (T), R5.2
LED-SEG-U: D1.5 (U), D2.5 (U), R4.2
unnamed: L1.P$1 (1), U2.3 (SW)
unnamed: R3.2, U2.1 (EN)
unnamed: C3.2, R1.1, R2.2, U2.5 (VOUT/FB)
PA15: R20.1, U1.38 (PA15)
PB0: R18.1, U1.18 (PB0)
PB1: R10.1, U1.19 (PB1)
PB2: R11.1, U1.20 (PB2)
PB3: R17.1, U1.39 (PB3)
PB4: R16.1, U1.40 (PB4)
PB5: R7.1, U1.41 (PB5)
PB6: R8.1, U1.42 (PB6)
PB7: R15.1, U1.43 (PB7)
PB8: R9.1, U1.45 (PB8)
PB9: R19.1, U1.46 (PB9)
PB10: R14.1, U1.21 (PB10)
PB11: R4.1, U1.22 (PB11)
PB12: R6.1, U1.25 (PB12)
PB13: R5.1, U1.26 (PB13)
PB14: R13.1, U1.27 (PB14)
PB15: R12.1, U1.28 (PB15)
SERVO-CTRL: H2.3, R25.1, T1.1 (D)
SERVO-PWM: T1.3 (G), U1.29 (PA8)
SWCLK: H1.4, U1.37 (PA14)
SWDIO: H1.2, U1.34 (PA13)
USER_BUTTON: SW1.3 (1), SW1.4 (1), U1.2 (PC13)
V2_CHECK: R30.2, U1.4 (PC15)
VBAT: C1.1, C9.1, H2.2, R3.1, R25.2, S1.3, U2.4 (VIN)
VBATIN: H4.1, S1.2

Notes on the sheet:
RIGHT EYE
LEFT EYE
(3.3V - 2V) / 270 ohms = 5 mA
SERVO DRIVE
ESP8266
ESP POWER SWITCH
PGM/DEBUG HEADER
BADGELIFE SHITTY ADD-ON HEADER
VOLTAGE REGULATOR
STM32F030C6T6TR IN VERSION 2 (32 KB)

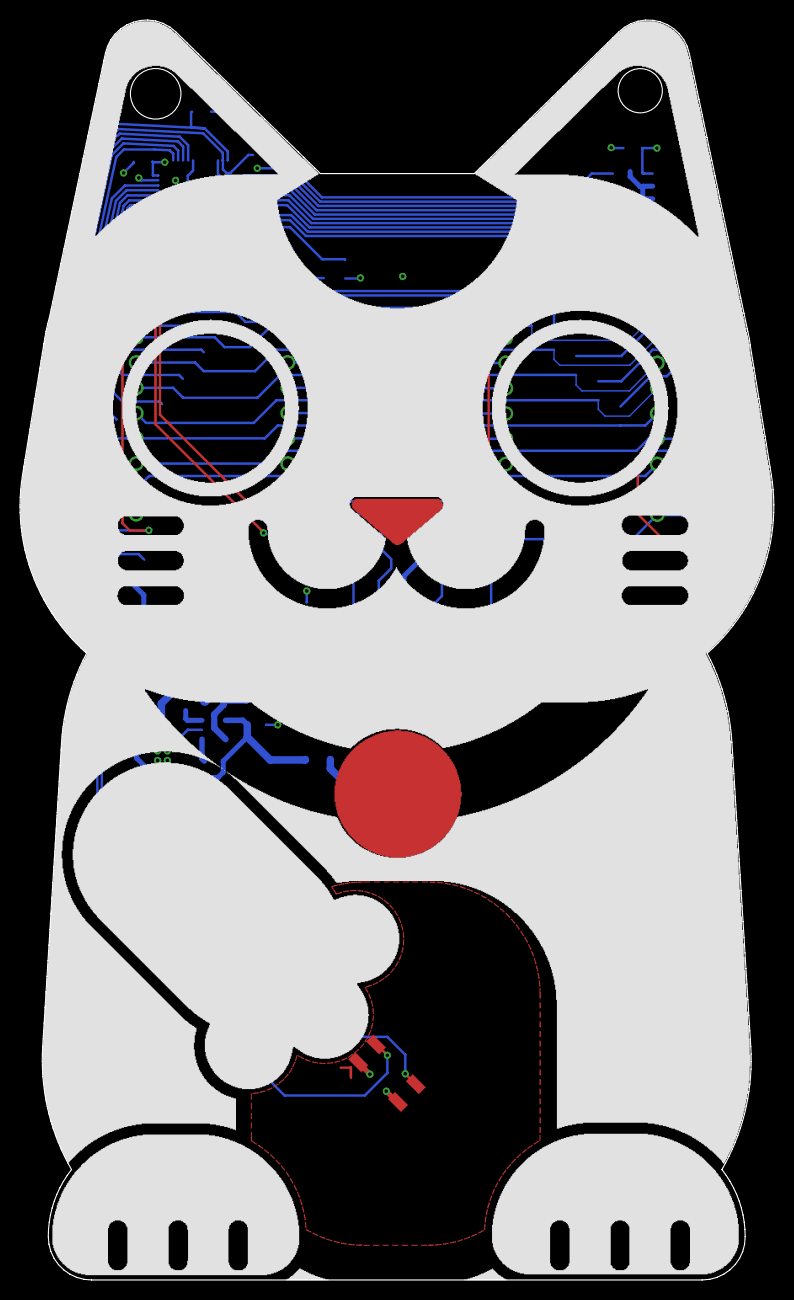
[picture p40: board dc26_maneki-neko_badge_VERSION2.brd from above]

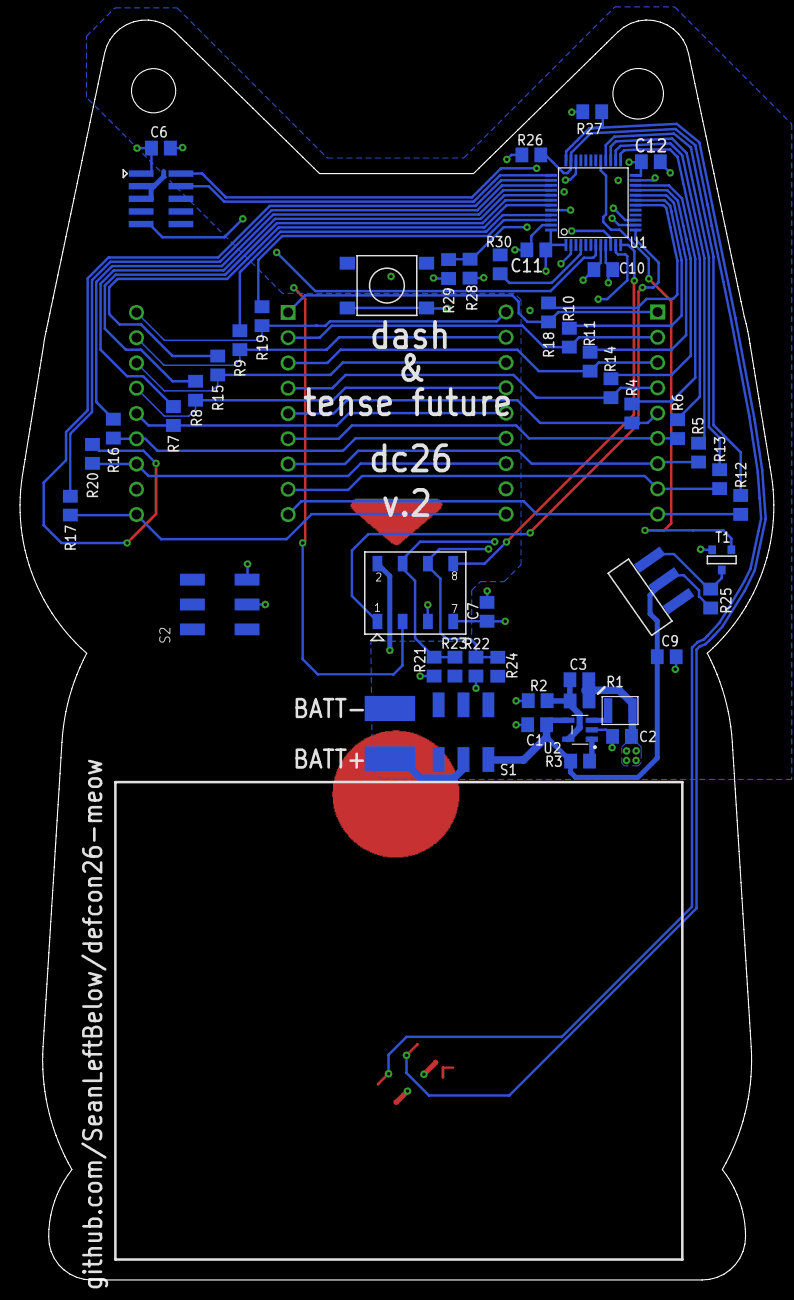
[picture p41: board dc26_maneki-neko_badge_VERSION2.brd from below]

Board: 4 copper layers, 75.8 x 126.7 mm, 53 parts (50 on the bottom side), 58 nets.

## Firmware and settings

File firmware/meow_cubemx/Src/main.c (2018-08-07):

/**
  ******************************************************************************
  * @file           : main.c
  * @brief          : Main program body
  ******************************************************************************
  ** This notice applies to any and all portions of this file
  * that are not between comment pairs USER CODE BEGIN and
  * USER CODE END. Other portions of this file, whether 
  * inserted by the user or by software development tools
  * are owned by their respective copyright owners.
  *
  * COPYRIGHT(c) 2018 STMicroelectronics
  *
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
  ******************************************************************************
  */
/* Includes ------------------------------------------------------------------*/
#include "main.h"
#include "stm32f0xx_hal.h"

/* USER CODE BEGIN Includes */

#include <math.h>
#include <stdbool.h>
#include <stdlib.h>
#include <stdio.h>

/* USER CODE END Includes */

I2C_HandleTypeDef hi2c2;

TIM_HandleTypeDef htim1;
TIM_HandleTypeDef htim3;

/* USER CODE BEGIN PV */

uint8_t servo_position = 10;
int seconds = 0;
bool ledFlag = false;
uint16_t eyesOpen = 0xC699; // outer perimeter on
uint16_t eyesHappy = 0x0CC0; // upper bucket on
uint16_t eyesClosed = 0x0840; // middle horizontal on
uint16_t eyesStars = 0x3966; // all inside bars on

/* USER CODE END PV */

void SystemClock_Config(void);
static void MX_GPIO_Init(void);
static void MX_I2C2_Init(void);
static void MX_TIM1_Init(void);
static void MX_TIM3_Init(void);
                                    
void HAL_TIM_MspPostInit(TIM_HandleTypeDef *htim);
                                

/* USER CODE BEGIN PFP */

void neko_led_test(void);
void neko_servo_setDuty(uint8_t);
void neko_waveAnimation(void);
void neko_blinkOnceAnimation(void);
void neko_blinkTwiceAnimation(void);
/* USER CODE END PFP */

/**
  * @brief  The application entry point.
  *
  * @retval None
  */
int main(void)
{
  /* MCU Configuration----------------------------------------------------------*/

  /* Reset of all peripherals, Initializes the Flash interface and the Systick. */
  HAL_Init();

  /* Configure the system clock */
  SystemClock_Config();

  /* Initialize all configured peripherals */
  MX_GPIO_Init();
  MX_I2C2_Init();
  MX_TIM1_Init();
  MX_TIM3_Init();
  /* USER CODE BEGIN 2 */

	HAL_GPIO_WritePin(GPIOB, GPIO_PIN_0|GPIO_PIN_1|GPIO_PIN_2|GPIO_PIN_10 
											|GPIO_PIN_11|GPIO_PIN_12|GPIO_PIN_13|GPIO_PIN_14 
											|GPIO_PIN_15|GPIO_PIN_3|GPIO_PIN_4|GPIO_PIN_5 
											|GPIO_PIN_6|GPIO_PIN_7|GPIO_PIN_8|GPIO_PIN_9, GPIO_PIN_SET); //turn off all leds
	neko_led_test();
	//neko_waveAnimation();
	HAL_GPIO_WritePin(GPIOB, GPIO_PIN_0|GPIO_PIN_1|GPIO_PIN_2|GPIO_PIN_10 
										|GPIO_PIN_11|GPIO_PIN_12|GPIO_PIN_13|GPIO_PIN_14 
										|GPIO_PIN_15|GPIO_PIN_3|GPIO_PIN_4|GPIO_PIN_5 
										|GPIO_PIN_6|GPIO_PIN_7|GPIO_PIN_8|GPIO_PIN_9, GPIO_PIN_SET); //turn off all leds

	HAL_TIM_PWM_Start(&htim1, TIM_CHANNEL_1);
	neko_waveAnimation();
	TIM_HandleTypeDef    TimHandle;
	
	// this was the magic to get the timer started + enable the interrupt
	// everything else came from cubemx generated code
	HAL_TIM_Base_Start_IT(&htim3); //start hardware timer 3 in interrupt mode

	
	
  /* USER CODE END 2 */

  /* Infinite loop */
  /* USER CODE BEGIN WHILE */
  while (1)
  {
		HAL_GPIO_WritePin(GPIOB, 0xFFFF, GPIO_PIN_SET); // no eyes
		HAL_GPIO_WritePin(GPIOB, eyesOpen, GPIO_PIN_RESET); // open eyes
		
		if(ledFlag)
		{
			if(seconds % 60 == 0)
			{
				neko_waveAnimation();
			}
			
			if(seconds % 7 == 0)
			{
				neko_blinkOnceAnimation();
			}			
			
			if(seconds % 11 == 0)
			{
				neko_blinkTwiceAnimation();
			}
			ledFlag = false;
		}
		
		
		
		
		
  /* USER CODE END WHILE */

  /* USER CODE BEGIN 3 */

  }
  /* USER CODE END 3 */

}

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
/* USER CODE BEGIN 4 */

// i believe this gets called for all timer interrupts and the if statement filters them out
void HAL_TIM_PeriodElapsedCallback(TIM_HandleTypeDef *htim)
{
    if (htim->Instance == htim3.Instance)
    {
			//HAL_GPIO_TogglePin(GPIOA, GPIO_PIN_15);
			seconds++;
			ledFlag = true;
    }
}

void neko_led_test(void)
{
	
	int delaytime = 50;
	HAL_GPIO_WritePin(GPIOA, GPIO_PIN_6|GPIO_PIN_7, GPIO_PIN_SET); // enable right (a6) and left (a7) eyes
	
	for(int i=0; i<16; i++) // cycle though all segments on port B 
	{
		HAL_GPIO_WritePin(GPIOB, pow(2, i), GPIO_PIN_RESET); // turn on single segment
		HAL_Delay(delaytime); //delay in milliseconds
		//HAL_GPIO_WritePin(GPIOB, pow(2, i), GPIO_PIN_SET); // turn off single segment
	}
	HAL_GPIO_WritePin(GPIOB, GPIO_PIN_15, GPIO_PIN_SET); // turn off last segment
	
	// test dot segment
	HAL_GPIO_WritePin(GPIOA, GPIO_PIN_15, GPIO_PIN_RESET);
	HAL_Delay(delaytime);
	HAL_GPIO_WritePin(GPIOA, GPIO_PIN_15, GPIO_PIN_SET);
	
}

void neko_servo_setDuty(uint8_t value)
{
	if ((value >= 10)||(value <= 20))
	{
		__HAL_TIM_SET_COMPARE(&htim1, TIM_CHANNEL_1, value); // target 1 msec
	}
}


void neko_waveAnimation(void)
{
	HAL_GPIO_WritePin(GPIOB, 0xFFFF, GPIO_PIN_SET); // no eyes
	HAL_GPIO_WritePin(GPIOB, eyesStars, GPIO_PIN_RESET);
	for(int i = 0; i<3; i++)
	{
		neko_servo_setDuty(180);
		HAL_Delay(400);
		neko_servo_setDuty(190);
		HAL_Delay(400);
	}
}

void neko_blinkOnceAnimation(void)
{
	HAL_GPIO_WritePin(GPIOB, 0xFFFF, GPIO_PIN_SET); 
	HAL_GPIO_WritePin(GPIOB, eyesClosed, GPIO_PIN_RESET); 
	HAL_Delay(75); 
}

void neko_blinkTwiceAnimation(void)
{
	HAL_GPIO_WritePin(GPIOB, 0xFFFF, GPIO_PIN_SET); 
	HAL_GPIO_WritePin(GPIOB, eyesClosed, GPIO_PIN_RESET); 
	HAL_Delay(75);
	HAL_GPIO_WritePin(GPIOB, 0xFFFF, GPIO_PIN_SET); 
	HAL_GPIO_WritePin(GPIOB, eyesOpen, GPIO_PIN_RESET); 
	HAL_Delay(300);
	HAL_GPIO_WritePin(GPIOB, 0xFFFF, GPIO_PIN_SET); 
	HAL_GPIO_WritePin(GPIOB, eyesClosed, GPIO_PIN_RESET); 
	HAL_Delay(75);
}

/* USER CODE END 4 */
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


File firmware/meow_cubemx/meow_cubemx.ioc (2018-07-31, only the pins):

Mcu.UserName=STM32F030C8Tx
PA0.Signal=GPIO_Output
PA1.Signal=GPIO_Output
PA10.Signal=GPIO_Input
PA11.Signal=GPIO_Input
PA12.Signal=GPIO_Input
PA13.Signal=SYS_SWDIO
PA14.Signal=SYS_SWCLK
PA15.Signal=GPIO_Output
PA2.Signal=USART2_TX
PA3.Signal=USART2_RX
PA4.Signal=GPIO_Input
PA5.Signal=GPIO_Output
PA6.Signal=GPIO_Output
PA7.Signal=GPIO_Output
PA8.Signal=S_TIM1_CH1
PA9.Signal=GPIO_Output
PB0.Signal=GPIO_Output
PB1.Signal=GPIO_Output
PB10.Signal=GPIO_Output
PB11.Signal=GPIO_Output
PB12.Signal=GPIO_Output
PB13.Signal=GPIO_Output
PB14.Signal=GPIO_Output
PB15.Signal=GPIO_Output
PB2.Signal=GPIO_Output
PB3.Signal=GPIO_Output
PB4.Signal=GPIO_Output
PB5.Signal=GPIO_Output
PB6.Signal=GPIO_Output
PB7.Signal=GPIO_Output
PB8.Signal=GPIO_Output
PB9.Signal=GPIO_Output
PC13.Signal=GPIO_Input
PF6.Signal=I2C2_SCL
PF7.Signal=I2C2_SDA

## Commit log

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2018-05-25 Some older stuff
    [Untitled.kicad_pcb, Untitled.sch]
2018-05-25 Updates to move computers.
    [Untitled.sch, meow.kicad_pcb, meow.sch]
2018-06-04 Adding Art and kiCAD
    [meow.sch]
2018-06-09 initial commit of eagle files, schematics 95%
    [dc26_maneki-neko_badge_page01_201806072332.brd, dc26_maneki-neko_badge_page01_201806072332.sch]
2018-06-10 board outline in, some minor edits to schematic, board ready for component placement
    [dc26_maneki-neko_badge_page01_201806072332.brd, dc26_maneki-neko_badge_page01_201806072332.sch, meow_v4_boardoutline.dxf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]
2018-06-11 some component placement, eyes locked in
    [dc26_maneki-neko_badge_page01_201806072332.brd, meow_v4_eyes.dxf]
2018-06-13 more layout. changed out connectors to support a clean 'art' (top) side. shooting for 2 layers, might need to be 4 to avoid a ton of routing time.
    [dc26_maneki-neko_badge_page01_201806072332.brd, dc26_maneki-neko_badge_page01_201806072332.sch]
2018-06-14 completely regretting my decision to use eagle
    [dc26_maneki-neko_badge_page01_201806072332.brd, dc26_maneki-neko_badge_page01_201806072332.sch]
2018-06-14 mini commit before taking a shower and letting autorouter mess around
    [dc26_maneki-neko_badge_page01_201806072332.brd, dc26_maneki-neko_badge_page01_201806072332.sch]
2018-06-15 re-orging traces to eyes for clean routing, done routing left eye
    [dc26_maneki-neko_badge_page01_201806072332.brd, dc26_maneki-neko_badge_page01_201806072332.sch]
2018-06-17 all led and high(er) speed signals routed... phewf
    [dc26_maneki-neko_badge_page01_201806072332.brd, dc26_maneki-neko_badge_page01_201806072332.sch]
2018-06-18 pcb traces routed, just need to finish off GND and 3V3 rails
    [dc26_maneki-neko_badge_page01_201806072332.brd, dc26_maneki-neko_badge_page01_201806072332.sch]
2018-06-20 finished routing incl 3v3 and gnd, except shitty addon connector (will route after artwork is added
    [dc26_maneki-neko_badge_page01_201806072332.brd]
2018-06-23 update gitignore, add intermediate art files, update layout file
    [dc26_maneki-neko_badge_page01_201806072332.brd, meow_v4_eyes.dxf, meow_v4_red_fills.dxf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]
2018-06-24 added copper art (nose, collar tag, and coin). just need to route shitty addon connector and i think its done
    [dc26_maneki-neko_badge_page01_201806072332.brd]
2018-06-25 silk fixed, drc errors fixed, going to export and send thru freedfm
    [dc26_maneki-neko_badge_page01_201806072332.brd, dc26_maneki-neko_badge_page01_201806072332.sch]
2018-06-26 updated design (smt servo connector), out to freedfm, quote from seeed
    [dc26_maneki-neko_badge_page01_20180626.brd, dc26_maneki-neko_badge_page01_20180626.csv, dc26_maneki-neko_badge_page01_20180626.sch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]
2018-06-27 adjusted ref des line thickness, created fab/assy pkg for vendor RFQs. this might be the final form....
    [dc26_maneki-neko_badge_page01_20180626.brd, dc26_maneki-neko_badge_page01_20180626_commas.csv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]
2018-06-27 added power switch and user button
    [dc26_maneki-neko_badge_page01_20180626.brd, dc26_maneki-neko_badge_page01_20180626.sch]
2018-06-29 OUT TO FAB OMG 2560256025602560
    [dc26_maneki-neko_badge_page01_20180626.brd, dc26_maneki-neko_badge_page01_20180626.sch, dc26_maneki-neko_badge_page01_20180626_centroid-PICKANDPLACE.csv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]
2018-07-11 adding in-progress for mini-meow add-on
    [mini_meow.kicad_pcb, mini_meow.sch]
2018-07-12 added ground
    [mini_meow.sch]
2018-07-13 added net list, updated schematic, layout
    [mini_meow.kicad_pcb, mini_meow.sch]
2018-07-14 moved back from 2 resistors to 1
    [mini_meow.sch]
2018-07-19 updated kicad for new layout
    [meow_v4.dxf, mini_meow.kicad_pcb, mini_meow.sch]
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2018-07-25 pcb update, added working art files
    [meow_v4-export.dxf, meow_v4-trace.dxf, meow_v4.dxf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]
2018-07-25 updated library, added copper images
    [meow_v5-thick outline-face.dxf, meow_v5-thick outline.dxf, mini_meow.kicad_pcb]
2018-07-25 updated pcb, maybe first final draft
    [mini_meow.kicad_pcb]
2018-07-26 updated copper layers. added ground
    [mini_meow.kicad_pcb]
2018-07-26 updated copper layers....again...
    [mini_meow.kicad_pcb]
2018-07-26 updated some silkscreen text
    [mini_meow.kicad_pcb]
2018-07-26 updated mask for copper
    [mini_meow.kicad_pcb, mini_meow.sch]
2018-07-27 added gerber files
    [mini_meow-B.Cu.gbl, mini_meow-B.Mask.gbs, mini_meow-B.SilkS.gbo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]
2018-07-28 ignore updates, blank firmware template update, pcb paw fix (coin cutout for paw)
    [dc26_maneki-neko_badge_standalone_20180726.brd, dc26_maneki-neko_badge_standalone_20180726.sch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]
2018-07-28 led test implemented in firmware. dunno why the whitesilk svg changed but committing anyway.
2018-07-31 interrupt working, trying to make it trigger waving animation, but interrupt handler doesnt like calling user functions 2 deep for some reason (or something else im not catching)
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2018-08-02 BOM stuff (#4)
    [dc26_maneki-neko_badge_page01_20180626.csv]
2018-08-07 60 seconds and servo fix.
    [main.c]
2018-08-18 Cleanup and README update
    [dc26_maneki-neko_badge_page01_20180626.csv, dc26_maneki-neko_badge_page01_20180626_commas.csv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]
2018-08-18 Art (#6)
    * created SAO Rev2 with correct connector orientation
    * updated kicad to display layers and fix silk rotation
    [mini_meow-B.Cu.gbl, mini_meow-B.Cu.gbr, mini_meow-B.Mask.gbr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]
2018-09-05 version 2 start, cost reduction edits to schematic
    [dc26_maneki-neko_badge_VERSION2.brd, dc26_maneki-neko_badge_VERSION2.sch, dc26_maneki-neko_badge_page01_201806072332.brd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]
2018-09-17 pcb v2 routed, bom edited, gerbers rendered - quote out to pcba house and dfm check to freedfm
    [dc26_maneki-neko_badge_VERSION2.brd, dc26_maneki-neko_badge_VERSION2.sch, dc26_maneki-neko_badge_VERSION2_updated.csv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]
2018-10-29 revised gerbers (#8)
    [mini_meow-B.Cu.gbl, mini_meow-B.Mask.gbs, mini_meow-B.SilkS.gbo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]

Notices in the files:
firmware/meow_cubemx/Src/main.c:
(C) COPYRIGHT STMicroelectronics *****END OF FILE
